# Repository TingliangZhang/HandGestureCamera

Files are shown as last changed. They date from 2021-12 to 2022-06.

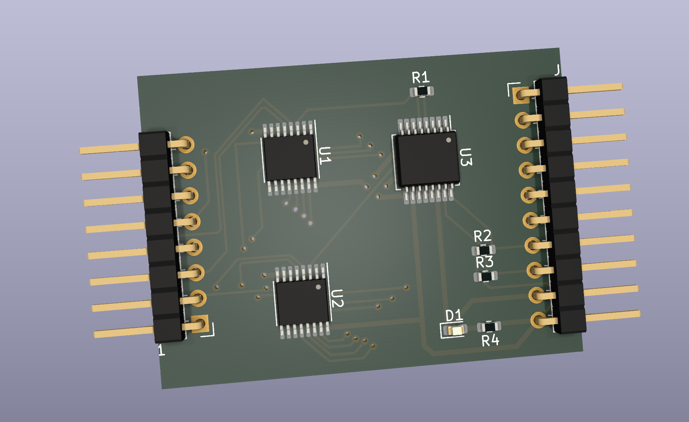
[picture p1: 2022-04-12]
宣传素材/屏幕截图 2022-04-12 194014.png

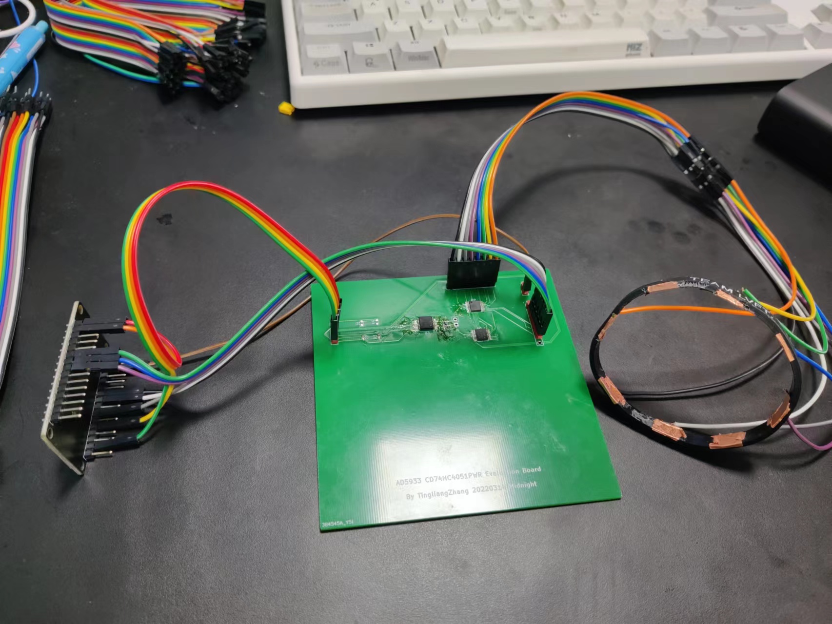
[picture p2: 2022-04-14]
宣传素材/手环V1实物图.jpg

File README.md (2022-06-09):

# HandGestureCamera

## BP相关

主控芯片及PCB上外围电路 约100 其中包括：

| 名称 | 作用 | 估算BOM价格/RMB |
| --- | --- | --- |
| ESP32-WROOM | 主控兼Wifi+蓝牙通信 | 13 |
| 网络分析仪或FPGA替代品  | 测量阻抗 | 20-100 |
| 高频多路选通器 | 两两选通电极 | 5x2 |
| PCB SMT及供电等部分元件 | 集成化 | 10 |

电极及外壳代工 10 

物流及营销费用 10

## 肌电技术方案

测试仪器：[LCR/阻抗分析仪](https://www.hioki.cn/html/methods/power.html)

LCR是单一频率下的阻抗分析仪

复现一款PCB：

[AD5933](https://www.analog.com/cn/products/ad5933.html)+[ADG1608](https://www.analog.com/cn/products/adg1608.html) 

AD5933

I2C通信

ADG1608

EN高电平使能 A2A1A0选通 每片占用4pin数字输出

Arduino采用[Seeed XIAO RP2040](https://www.seeedstudio.com/XIAO-RP2040-v1-0-p-5026.html)

3+3+EN数字输出，2xI2C，2xUART，正好占满qwq

或者希望引脚宽裕一点直接用[Raspberry Pi Pico](https://www.raspberrypi.com/documentation/microcontrollers/raspberry-pi-pico.html)，还更便宜，但是只有3.3V，PCB这边我I2C用的5V

但是由于RP2040 MCU电压就是3.3，其实XIAO的I2C也不一定能work，Arduino板同理

ADG1608额定电源电压：±15 V/12 V/±5 V，3 V逻辑兼容输入，目前PCB设计可能有问题，单5V输入可能会导致开关出错

想用CD74HC4051这种 8:1, 1-channel analog mutliplexer 单通道模拟多路复用器

首先绝对不能用TMUX1308这种数字多路复用器

其他要考虑的事情：

其次驱动电压

内阻

支持的最大电流

备选项包括：ADG1408YRUZ、CD4051B

参考文档 [ 多路复用器和信号开关词汇表 (Rev. B)](https://www.ti.com.cn/cn/lit/pdf/zhcaad5) 中的解释，可以知道，其实8：1双通道模拟多路复用器更适合，如[CD4097B](https://www.ti.com/product/CD4097B) - 20-V, 8:1 differential, 1-channel analog multiplexer，或 [MUX36D08](https://www.ti.com.cn/product/cn/MUX36D08) - 1pA 开路泄漏电流、36V、8:1 精密模拟多路复用器

在TI的[模拟开关 & 多路复用器](https://www.ti.com.cn/zh-cn/switches-multiplexers/analog/overview.html)中可以挑选，

[TMUX1108](https://www.ti.com.cn/product/cn/TMUX1108) - 3pA 导通状态泄漏电流、5V、±2.5V、8:1、单通道精密多路复用器

[TMUX1208](https://www.ti.com.cn/product/cn/TMUX1208) - 具有 1.8V 输入逻辑的 5V、8:1、单通道通用模拟多路复用器

[TMUX1308](https://www.ti.com.cn/product/cn/TMUX1308) - 具有 1.8V 逻辑电平控制的 5V、8:1、单通道通用多路复用器

最终选定：[TMUX1208](https://www.ti.com.cn/product/cn/TMUX1208) 或 [CD74HC4051](https://www.ti.com.cn/product/cn/CD74HC4051)

[CD74HC4051PWR](https://item.szlcsc.com/328685.html) jlc充足现货，可以优先，另购买平替[74HC4051M/TR SOP-16](https://item.szlcsc.com/520618.html)作为备用，但是封装不同，画两个不同的板子或在同一个板子上面画两个方案。

即[CD74HC4051PWR TSSOP-16](https://item.szlcsc.com/328685.html) + [74HC4051M/TR SOP-16](https://item.szlcsc.com/520618.html) 方案

## Arduino

[arduino-ad5933](https://github.com/mjmeli/arduino-ad5933)

用[Seed XIAO RP2040](https://wiki.seeedstudio.com/XIAO-RP2040/) with Arduino不行，没输出

用[ESP32-DevKitC](https://www.espressif.com/en/products/devkits/esp32-devkitc/overview) with Arduino行，一下子就跑通了，调高波特率到115200还贼快，一句话：ESP32牛逼

ESP32开发板接线：SCL-D22、SDA-D21，5V-VIN，GND-GND

Timer参考ESP32 Arduino Example中的ESP32-Timer-Repeat Timer例程，设置定时器

20220406 Debug了一下午，发现俩问题：写switch不写break、Enable电平搞错了。一句话我是傻子。。。

[CD74HC4051 数据表、产品信息和支持| 德州仪器TI.com.cn](https://www.ti.com.cn/product/cn/CD74HC4051) Debug，发现是低电平Enable，之前板子画错了qwq，现在接了一根GND到板子的EN上面，就好了

| ENABLE | S2 | S1 | S0 | ON CHANNEL |
| --- | ---- | ---- | ---- | --- |
| L | L | L | L | A0 |
| L | L | L | H | A1 |
| L | L | H | L | A2 |
| L | L | H | H | A3 |
| L | H | L | L | A4 |
| L | H | L | H | A5 |
| L | H | H | L | A6 |
| L | H | H | H | A7 |
| H | X | X | X | None |

注意编码中S2是最高位！！！第一版本出错是因为编码反了。

gg，刚刚静电电了一下手环，我怀疑MUX被电坏了或者是芯片完蛋了。。。Z变成了3-4w，最低1w

刚刚换成Mega2560测试了一圈，感觉还是采样频率的问题，Frequency越小，比如1kHz，扫描速度越慢。现在调成10kHz甚至20kHz就好很多了，累加一次，准确度目前看是够用的

## Python数据读取和可视化

用[JupyterLab](https://jupyter.org/)+[Plotly Python Graphing Library](https://plotly.com/python/)做可交互的实时数据可视化。

Pyserial读取收到的数据，以下为数据格式的说明

```
0:1
90: R=348/I=1914  |Z|=102512.95
100: R=102/I=2118  |Z|=93806.21
Frequency sweep complete!
```

A:B 从0-8端口中选通两个，测量这两个端口之间的阻抗。

100: / 101: 当前扫描频率，单位为kHz

R/I  中间原始数据的实部虚部

|Z| 测得的阻抗数据，可以进行归一化，由于短路情况下|Z|= REF_RESIST 即10000

想要更简洁的数据，可以修改ino文件，比如0:1 10000 \n

由于AD5933扫描速度的限制，一次扫描约耗时1.5s

Plotly Python Open Source Graphing Library 示例

[2D Histograms](https://plotly.com/python/2D-Histogram/) 二维直方图表示可视化后的二维空间分布

[Histograms](https://plotly.com/python/histograms/) 为原始数据的可视化直方图，28个数据按照两两之间距离从小到大有序排列

[ML Regression](https://plotly.com/python/ml-regression/) 训练过程和效率可视化

## 应用方向

AR手势识别

手语识别

健康管理：

Use [Skulpt](https://www.skulpt.me/) to measure your body fat percentage and get a personalized workout plan to burn fat and build muscle.

## 手势识别相机手环

使用两个位于手表位置的前视摄像头实时识别手势

用于AR设备的手势识别辅助

技术难点：

受限于手腕视角，只能看到骨骼突起和肌肉拉伸，以及偶尔出现的手指，做模式识别可能会比较困难，不同人可能要单独标定。

动态手势复杂度高，手指关节很多

手势数据集较少，我们这一特定的场景还需要单独采集数据集

手环所在位置一定程度上会影响识别的结果

技术方案：

数据集获取使用Leapmotion提取手势关节数据，结合两个摄像头采集到的信息作为训练集。

1.多模态输入

将若干帧光流图像连接在单张彩色图像的通道维度上，将其作为深度网络的输入，使得输入数据中既包含空间信息又携带时序信息，以此来实现动态手势识别

一个序列不同的模态携带不同的信息，RGB图片包含丰富的颜色和纹理信息，深度图片包含物体的轮廓和深度信息，光流分别描述了像素在x方向与y方向的运动信息。这些数据在信息描述上具有互补性，将它们融合起来，能够有效弥补单一模态数据的局限性。

基于RGB 序列和Depth序列和Flow序列的融合特征进行动态手势识别

2.手部检测器预处理

融合彩色和深度数据的双通道Faster R-CNN手部检测框架

3.基于人工特征的机器学习算法的动态手势建模

经典的方法有规整动态时间(Dynamic Time Warping, DTW)算法、隐马尔科夫模型(Hidden Markov Model, HMM)

这部分可以视能否直接得到手部数据来决定做不做

参考

https://image.hanspub.org/Html/19-1541767_35738.htm

https://www.hindawi.com/journals/tswj/2014/267872/

## 新的肌电方法

Tomo: Wearable, Low-Cost Electrical Impedance Tomography for Hand Gesture Recognition

https://dl.acm.org/doi/10.1145/2807442.2807480

金属电极+双选择器+网络分析仪芯片+ESP32+小锂电

https://www.youtube.com/watch?v=FqgwBc7cGZ8

能不能做连续的

下垂和举起手是否能够鲁棒识别

其他身体部分，比如袜子

这一作老哥后来还做了手表周围的另一只手的触摸识别

https://dl.acm.org/doi/10.1145/2984511.2984568

以及手指是否摸到皮肤的识别

https://dl.acm.org/doi/10.1145/3332165.3347869

和一些导电物体周围贴上电极的识别

https://dl.acm.org/doi/10.1145/3025453.3025842

## 新的想法-手语识别

目标是识别中文手语，关于中文手语的科普参考 [回形针Vol.154 手语的秘密](https://www.youtube.com/watch?v=vpkHTLhuDqg)

发现手语包括手部动作、肢体语言、面部表情

目前ASL图像识别方面做的比较好的是国外的[SignAll](https://www.signall.us/)，看图片是一个Kinect2和俩Realsense D435i，还有一个铁架子打光+架设摄像头，使用者要戴上一个五彩斑斓的手套。国内则是[腾讯优图发布的AI手语翻译机](https://cloud.tencent.com/developer/article/1430241)通过单摄像头识别，但是看起来需要很高的算力，DEMO用的是外星人的笔记本。

其实可以先做ABC的识别：这个是一个很傻的一个一个字母翻译的网页[English to Sign Language (ASL) Translator](https://wecapable.com/tools/text-to-sign-language-converter/)

[Hand Talk Translator](https://play.google.com/store/apps/details?id=br.com.handtalk)是逆向的转换，从文本到动漫人物动作的转换，国内类似产品是[搜狗AI开发平台手语数字人](https://ai.sogou.com/solution/signlanguage_digitalman/)

[手语也能机器翻译了！机器学习手势识别功能了解一下](https://blog.51cto.com/u_14815220/3451551) 华为机器学习（ML Kit）提供手部关键点识别服务，可用于手语识别。手部关键点识别服务能识别手部21个关键点，通过每个手指的方向和手语规则作比较去找手语字母表。

后期可以做根据国家通用手语词典来做8k+的词组识别。

申专利、发顶会、打比赛

## 竞品

[Tenzr: A Fun and Efficient Way to Regain Mobility and Function](https://tenzrhealth.com/) 主打手腕康复，就离谱，感觉是智商税，技术方案是IMU

[TENZR, the next generation gesture recognition wrist-band for VR AR, to be presented at CES 2018](https://www.prnewswire.com/news-releases/tenzr-the-next-generation-gesture-recognition-wrist-band-for-vr-ar-to-be-presented-at-ces-2018-300572362.html)

这个报告里面的BioInteractive Technologies Inc.和上一个是同一家智商税公司，所以这个只是个想法，没做。

[Myo Gesture Control Armband review](https://www.digitaltrends.com/pc-accessory-reviews/myo-gesture-control-armband-review/) EMG原理，很多年前就比较完善了，但是已经停产了xs，估计无了

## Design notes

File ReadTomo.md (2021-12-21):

Tomo: Wearable, Low-Cost Electrical Impedance Tomography for Hand Gesture Recognition

https://dl.acm.org/doi/10.1145/2807442.2807480

是否需要像[Touché](https://dl.acm.org/doi/10.1145/2207676.2207743)一样去扫频

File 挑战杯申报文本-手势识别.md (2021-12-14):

# 挑战杯项目申报-手势识别

SignWatch：一种基于断层扫描的可穿戴手势识别

[第40届挑战杯报名开始-清华美院艺协](https://mp.weixin.qq.com/s/xyTMBz-5uR9o7P9dYUQgTA)

## 创新性产品或服务简介

中国有2700万以上的聋哑人，他们主要使用手语进行交流。近年来国内外研究机构和企业逐渐开始关注手语翻译的可能性，目前较为成熟的方向是深度摄像头视觉识别，但是这种方法需要较多的外部设备，如多个深度摄像头、补光灯、性能强大的PC以及固定上述设备的支架，无法应用在日常交流中。本项目提出了一种基于断层扫描的穿戴式手势识别，借鉴CT、PET、MRI（核磁共振）等医学影像设备使用的断层扫描算法，通过环状排布的电极采集阻抗信息逆推肌肉收缩情况，从而实现使用可穿戴手环识别手势，进一步结合手臂状态实现手语实时翻译。可穿戴手语翻译能够帮助手语使用者在日常生活中与其他语言使用者进行交流，有着广阔的应用前景、众多的目标用户和极大的社会价值。

## 项目市场前景和社会效益预测分析

中国有2700万以上的聋哑人，这一数字还在不断增长，作为占中国人口近2%的群体，另据WHO估计，到2050年，全球将有超过7亿人，即十分之一人口，发生残疾性听力损失。但我们在生活中很少见到他们，一个重要的原因就是听觉功能障碍者或言语功能障碍者使用手语作为常用的沟通方式，手语作为一种独立语言，学习成本较高，急需一款能够打通中英文使用者和手语使用者之间语言屏障的产品出现，来帮助手语使用者更好的融入社会。

本项目旨在提供一种绝大多数家庭可负担的可穿戴的手语翻译工具，并考虑到后续的更新换代，按照每人100美元计算，仅中国大陆就有约30亿美元的市场容量，如果考虑到连带服务和同样目标用户群体产品空间，这将是一个逾百亿美元的市场。

初期我们和特殊学校合作，在测试迭代产品的同时，了解听觉功能障碍者或言语功能障碍者的需求，也为中国的特殊群体尽自己的一份力。

## 创业团队基本情况

本团队成员均来自清华大学美术学院，团队成员有工科、设计双背景，有着丰富的交互设备开发相关项目的经验。

团队曾获得清华挑战杯特奖、清华校友三创大赛总决赛种子组十强、互联网+创新创业大赛北京市十佳团队、中美青年创客大赛全国总决赛优胜奖，是一支久经沙场的创新创业团队。

万雪鸽，美院产品设计专业在读，具备优秀的设计思维和熟练的设计技能。曾立项过两次国家级大学生创业创新项目计划、两次产品设计相关的srt并参与了完整的创新过程，具备交互设备开发、产品开发的能力和经验。

林易佳，美院产品设计专业在读，曾参加过挑战杯大赛并取得三等奖。

粟艺薇，美术学院展示设计学生，具备产品设计思维能力及三维制作能力。曾立项创业实践项目，参加srt“基于人工智能的在线教育产品设计”交互界面设计，参与工艺美术馆空间展示设计，成渝铁路逻辑梳理及空间设计。

张庭梁，于2020年本科获清华大学电气工程及其自动化工程学士学位，清华大学美术学院信息艺术设计交叉学科研究生，目前在清华大学未来实验室。入选星火计划十二期（“科技创新，星火燎原”清华大学学生创新人才培养计划）。现任清华大学“未来通信”学生科技兴趣团队理事长，曾任清华大学“天空工场”学生科技兴趣团队“未来航空队”队长。2018年暑假在劳伦斯 - 伯克利国家实验室和加州大学伯克利分校 MSC Lab暑期研修。

曾获清华大学第38届“挑战杯”学生课外学术科技作品竞赛 特等奖、清华大学2020-2021年度优秀科技之星、第六届清华校友三创大赛总决赛 互联网与新媒体 种子组 十强奖、中美青年创客大赛全国总决赛 优胜奖、互联网 + 创新创业大赛北京市十佳团队、ABB大学生创新大赛全国总决赛三等奖(全国前六)等诸多科技创新创业奖项。

## 项目方案

手语（sign language、signed language、signing）是一种不使用听觉-语音，而使用视觉-手势模式——以肢体动作、脸部表情来表达传达意义意思使用的的语言。主要使用者和使用对象，是听觉功能障碍者或言语功能障碍者。对一般大众而言，手语不算通用；在聋聩人士的社群，手语则是相当常见的沟通方式。手语并非世界共通，手语会像口语一样，依照地区的不同，发展一套属于各该地区的手语。随着各种手语发展，如今有数百种手语在聋人社会中通用。

口语语言的必要成分是语音、词汇和语法。而手语就以不同的“手形”和动向代替了语音这部分的分工。有些地方的手语研究工作者会把基本手形加以编码（以美国手语字母为基础），情况就像口语语言使用者为每个音素标音，技术上，手语使用者就可以使用这些“音标”，再加上箭头以表示动向，作为以手语为本的简单的书面记录形式，而不需要动辄拍照或画图来作书面记录。虽然这种情况并不普遍，各地手语也暂没发展出以手语为本的规范通用文字，但技术上可行。邓慧兰编撰的《香港手语词典》(Hong Kong Sign Language: a trilingual dictionary)就以这种把基本手形编码的方法，作为词典的检索索引。

与大多数其他手语一样，中国手语（英语：Chinese Sign Language）主要是通过手势和动作结合面部表情来表达的。中国手语制定的目标是，解决中国各地的流行手语手势不一致、聋人学习科学文化知识及交往不便的问题。2018年7月1日，中国实施《国家通用手语常用词表》和《国家通用盲文方案》作为语言文字规范发布。2021年3月1日，国家语委语言文字规范《〈中华人民共和国国歌〉国家通用手语方案》（GF0024-2020）正式实施。

根据WHO统计，全球有15亿人患有某种程度的听力损失，其中约4.3亿人需要针对听力损失的康复服务。到2050年，预计将近25亿人有某种程度的听力损失，至少7亿人需要听力康复。听力丧失可能由遗传、出生时的并发症、某些传染病、慢性耳感染、暴露于大的声响、使用耳毒性药物和衰老引起。全世界人口的5%以上，即4.3亿人，需要康复治疗，以解决他们的残疾性听力损失（4.32亿成人，3400万儿童）。据估计，到2050年，将有超过7亿人，即十分之一人口，发生残疾性听力损失。

完整的手语包括手部动作、肢体语言、面部表情三部分，其中表达内容丰富度方面手部动作大于肢体语言大于面部表情，通过手部动作和上肢即可完成绝大部分的表意。目前穿戴式手势识别是整个流程中的技术难点所在。

我们提出使用环形均匀排布的8个电极作为采样点，通过两个8选1MUX依次选通其中两个电极，并使用网络分析仪监测这两个电极之间的实时阻抗，获得28个阻抗数据，使用图像重建算法重建截面的肌肉状态，从而获取目前手势。初步的实验已经证明此方法的科学性和可行性。

计算机体层成像（Computed Tomography，简称CT）又称计算机断层扫描，是一种影像诊断学的检查。这一技术曾被称为计算机轴向断层成像（Computed Axial Tomography）。它使用从不同角度进行的许多X射线测量值的计算机处理组合来生成特定扫描区域的横截面（断层）图像（虚拟“切片”） 物体，使用户无需切割即可看到物体内部。

正电子发射断层扫描（英语：Positron emission tomography，简称PET）简称正子断层造影、正电子成像术，是一种核医学临床检查的成像技术。PET技术是目前唯一的用解剖形态方式进行功能、代谢和受体显像的技术，具有无创伤性的特点并能提供全身三维和功能运作的图像。正电子发射计算机断层扫描既是医学也是研究的工具。在肿瘤学临床医学影像和癌扩散方面的研究方面有着大量的应用。

我们参考CT和PET的图像重建部分的算法，作为一种不完全数据采样，准确来说是稀疏角度均匀采样，稀疏角度重建问题图像重建方法中, 迭代重建最经典的方法是 Gorden等提出的代数重建法(algebra reconstruction technique, ART)，ART算法虽然适合投影数据不完全、投影角度缺失以及投影间隔不均匀等场合的图像重建, 但其计算量大, 重建速度慢。

2006 年 Candes 等 对 Kashin 提出的信号稀疏和逼近理论进行了深 入研究, 提出了一种新的信息获取理论-压缩感知 (compressed sensing, CS): 只要信号在某一个正交空间具有稀疏性, 就可以较低的频率采样信号高概率重构原始信号. 根据CS理论, 在迭代重建中 增加关于稀疏变换后图像的稀疏性约束, 可以解决内部问题、少视角问题等不完备投影数据的精确重建问题。

在以上算法的加持下，我们可以进一步消除噪声，获得更加清晰的肌肉断层扫描图像，从而实现趋于连续的手势识别，相比于离散的模式识别，在未来的进一步应用中更为普适。

同时我们这套系统还可以在AR、VR的手势识别中获得广泛应用，由于目前包括Hololens在内的AR眼镜都是通过前置摄像头识别手势，需要将手举起来才能操作，大大增加了用户的操作难度，手环或手表的识别是更自然更符合人机工程学的方式。

在进一步开发后，这一扫描可以方便的移植到其他场景，如脚踝、脖子等处，实现更为丰富的动作采集和应用。

## 项目实施风险预测及应对措施

可能会面临的产品竞争：项目目前市场上已有视觉相关解决方案，可能会产生竞争。我们团队有软硬件设计和产品设计的知识储备、经验，拥有的技术优势能够帮助我们更好的在市场上立足。更重要的是，本项目采用的断层扫描手势识别方案无需假设过多的外部设备，在佩戴手表和肩带的情况下即可进行手势识别，场景更加灵活，在一些日常生活交流场景中更是不二的选择。

可能面临的项目落地难题：可能难以打开市场或进行供应链管理。我们团队有从事过供应链管理和创业经验的成员，可以使我们少走弯路。

另外由于用户群体的特殊性，后续的测试及用户体验环节可能比较难开展：由于二作所在实验室——未来实验室常年从事无障碍设计，同时我们和一些特殊学校有密切的联系，在落地方面优势明显。

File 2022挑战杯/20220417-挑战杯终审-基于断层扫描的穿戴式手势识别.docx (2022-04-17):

基于断层扫描的穿戴式手势识别

万雪鸽 张庭梁 王喆隆 林易佳 粟艺薇

一、概述

本项目旨在设计一款可以实现手语实时翻译的手势识别智能手环，帮助手语使用者在日常生活中与其他语言使用者进行顺畅的交流。我们提出了一种基于断层扫描的穿戴式手势识别，借鉴借鉴CT、PET、MRI（核磁共振）医学影像设备使用的断层扫描算法，通过环状排布的电极采集阻抗信息逆推肌肉收缩情况，从而实现使用可穿戴手环识别手势，进一步结合手臂状态实现手语实时翻译。有着广阔的应用前景、众多的目标用户和较大的社会价值。

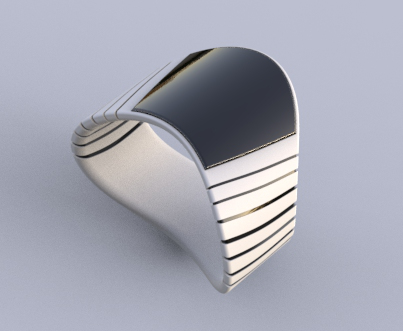
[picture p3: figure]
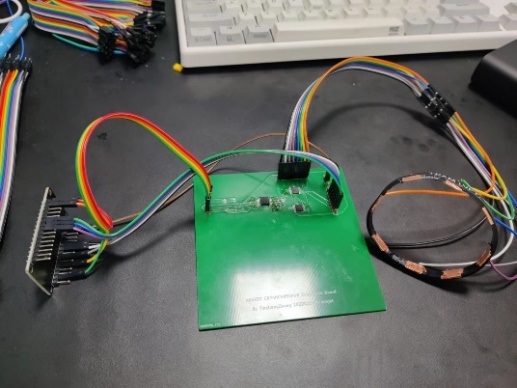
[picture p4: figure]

产品概念图 初代实体图

二、项目背景

1数量庞大的目标群体

根据全国第二次残疾人抽样调查数据，中国有2700万以上的聋哑人，大约占全国人口的2%，这一数字还在不断增长，另据WHO估计，到2050年，全球将有超过7亿人，即十分之一人口，发生残疾性听力损失。但我们在生活中很少见到他们，一个重要的原因就是听觉功能障碍者或言语功能障碍者使用手语作为常用的沟通方式，手语作为一种独立语言，学习成本较高，虽然我国信息无障碍领域的投入在逐渐增加，但全国致力于听障者专业服务人士仍只有约一万名，大部分公共服务没有配备专门的便利设施。所以我们急需一款能够打通中英文使用者和手语使用者之间语言屏障的产品出现，来帮助手语使用者更好的融入社会。

2当前手势识别技术的局限性

由于VR技术的兴起，近年来国内外研究机构和企业逐渐开始关注手识别，目前手势识别的方法主要分为肌电传感、摄像头图像识别、弯曲传感等几个方向，但是目前这些方法都存在一些问题导致他们不能被用在我们这一应用场景中，具体来说是肌电不准确、相机需要外置、弯曲传感体积太大而且不鲁棒。

而手语翻译的核心问题在于手势识别。目前到手势识别方式包括机电传感，摄像头图像识别，弯曲传感等方式。但是存在肌电信号不准确，相机需要外置，弯曲传感体积太大而且鲁棒性低等问题。以这款目前已经生产并使用的产品为例，如果想要获得精准的识别，需要有复杂的设备 清晰的光源和固定的场景

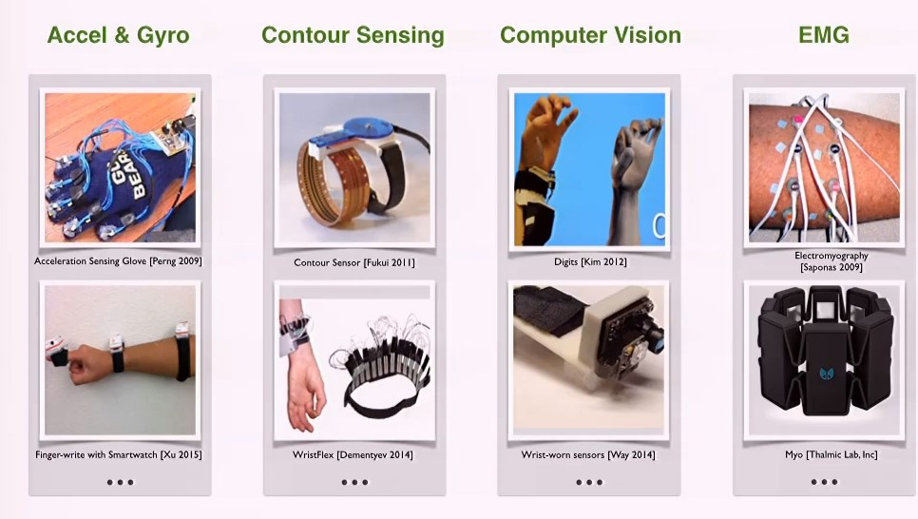
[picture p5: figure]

3 当前智能手语翻译设备

相关产品主要分为基于计算机视觉记录和基于数据的手套记录两种不同的类型。

对于听障人士来说，高昂的价格、笨重的设备、不精准的识别与翻译和有限的使用场景让以上产品难以在现实中使用。

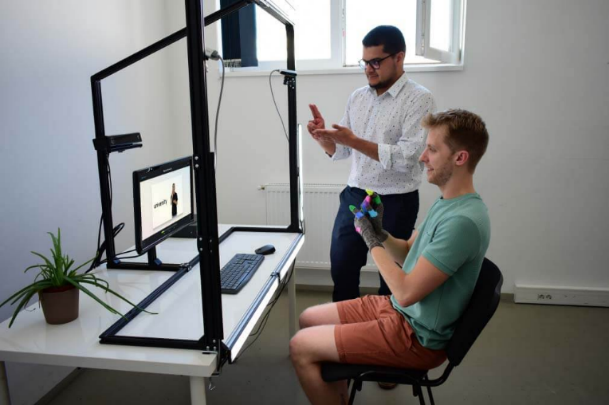
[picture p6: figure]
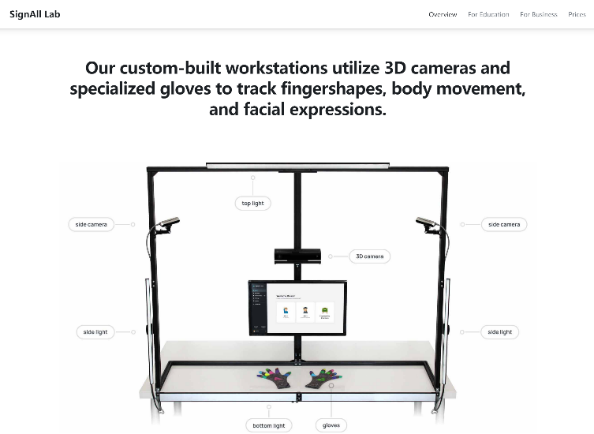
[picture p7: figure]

4 断层扫描技术应用的可行性

我们提出使用环形均匀排布的8个电极作为采样点，通过两个8选1MUX依次选通其中两个电极，并使用网络分析仪监测这两个电极之间的实时阻抗，获得28个阻抗数据，使用图像重建算法重建截面的肌肉状态，从而获取目前手势。初步的实验已经证明此方法的科学性和可行性。我们希望借助此技术给绝大多数手语使用者提供一种可负担的可穿戴的手语翻译工具。

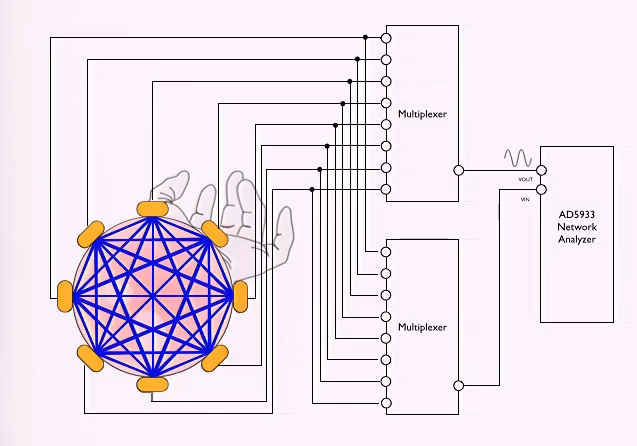
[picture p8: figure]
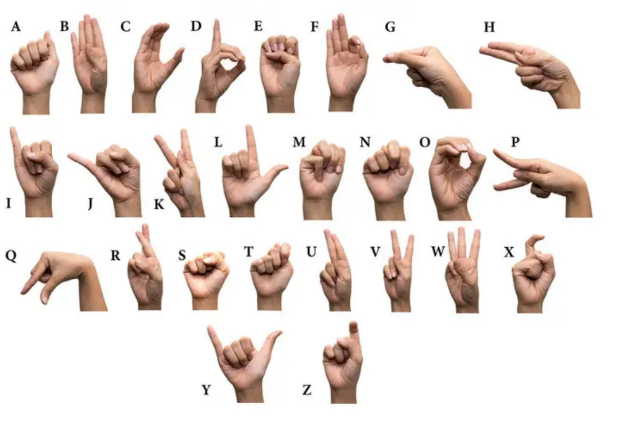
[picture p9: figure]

三、工作介绍

1 前期调研

手语是听觉功能障碍者或言语功能障碍者使用的交际工具，是人们利用手形、手的位置、手的移动、手掌的朝向，再配合以面部表情和身体姿态，按照一定的语法规则来表达特定的意思。对手语的识别不仅包括手部肌肉的捕捉与识别，还需要识别手臂的运动轨迹、左右手的相对位置、使用者的面部表情和手语与口语语义语法的自然转化，因此对手语的识别与翻译困难重重。

另外，手语并非世界共通，手语会像口语一样，依照地区的不同，发展一套属于各该地区的手语。随着各种手语发展，如今有数百种手语在聋人社会中通用。这也为手语的翻译增加了难度。

经过我们对手语的学习和系统梳理，我们发现在以上众多因素中，手语中手形变化的占比最多，左手是主要手，右手是辅助手，面部表情只做补充。另外由于手语因地域不同而有很大的变化，所以现在听障人士在遇到不会打的手语词汇时会使用手指字母代替，聋校教师也会以手指字母为媒介教导聋人口语与手语的转换，手指字母在听障人士间的使用频率很高。因此我们决定以26个手语字母为基础进行手语的识别与翻译。

2 嵌入式电路设计和制作

使用嵌入式芯片和高速ADC做阻抗采集

同时采用扫描的思路来获取各个方向的Tomography数据

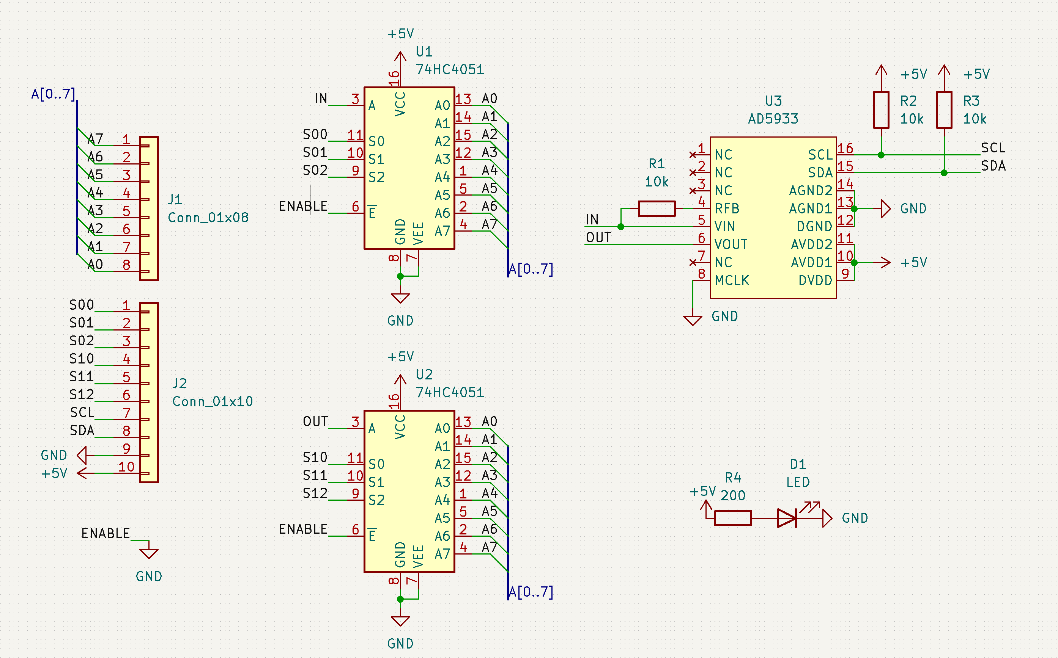
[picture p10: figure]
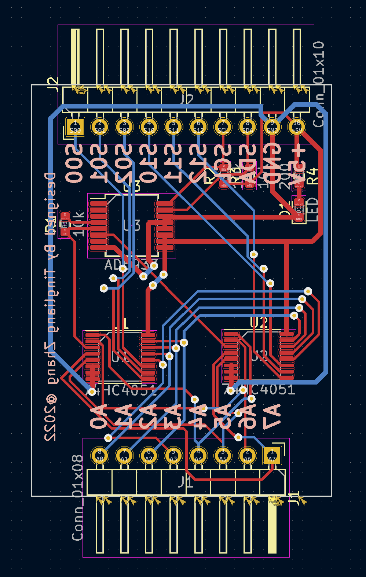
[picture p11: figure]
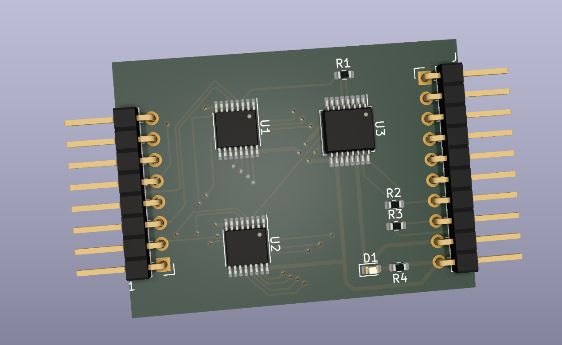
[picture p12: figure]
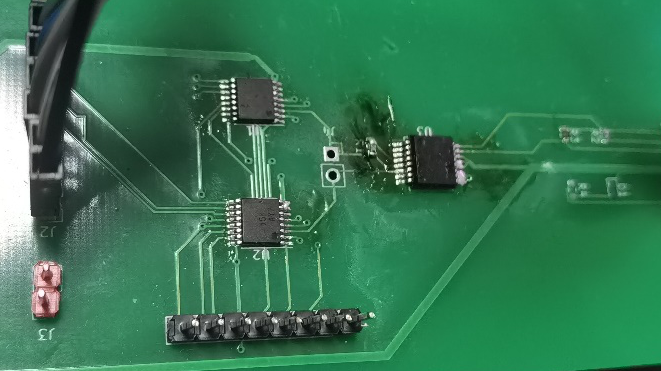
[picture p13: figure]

我们使用嵌入式芯片和高速ADC做阻抗采集，以上为手环小板原理图电路图和实物图，同时我们采用了扫描的思路来获取各个方向的Tomography数据：

3 手环产品设计

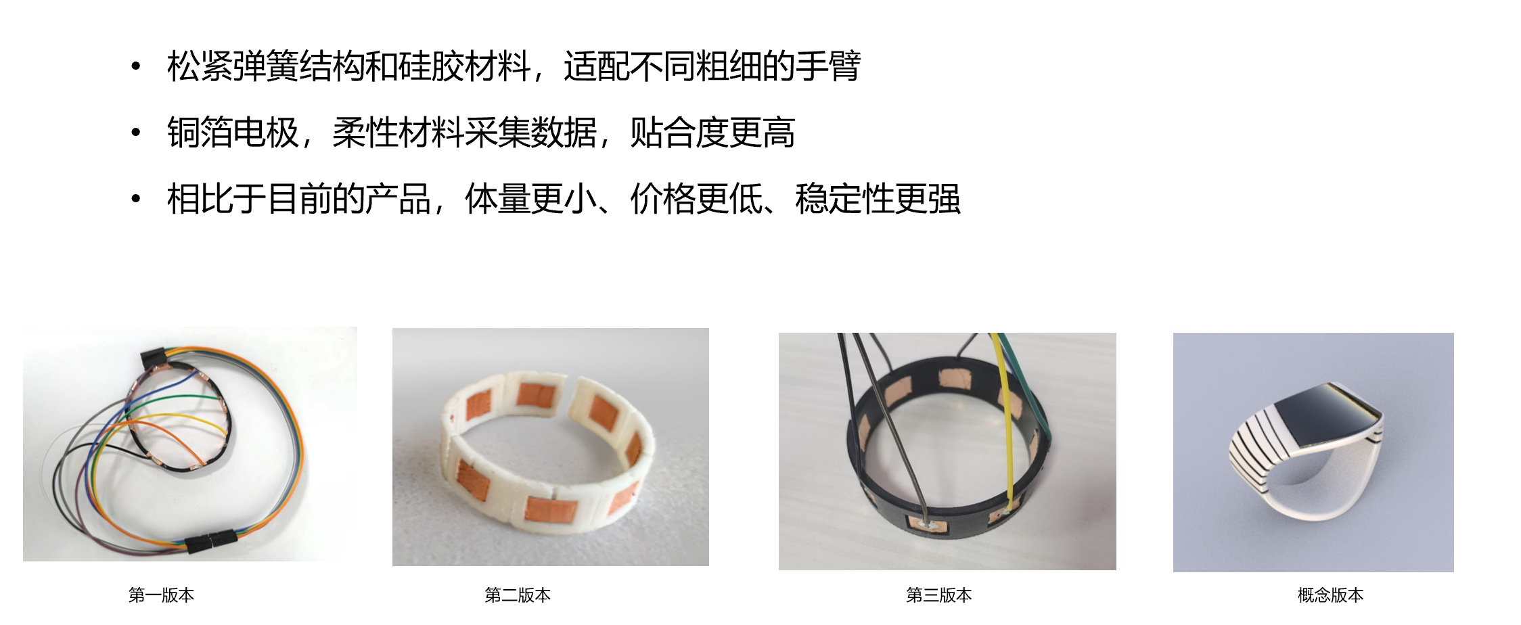
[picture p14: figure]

4 数据采集和可视化

我们使用上述嵌入式系统采集了大量训练数据并进行可视化和打标：

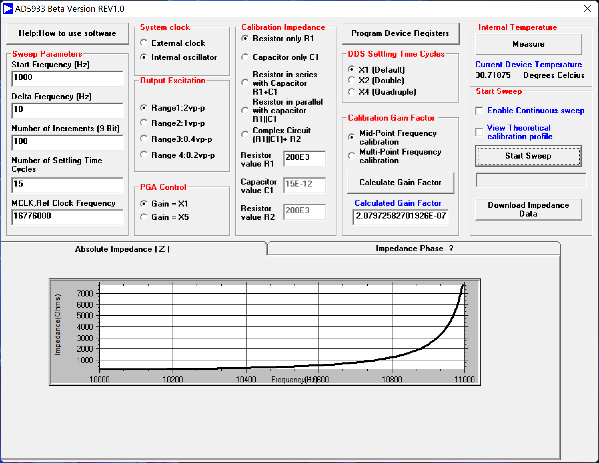
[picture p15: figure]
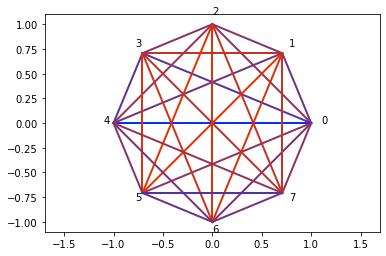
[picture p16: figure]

5 数据处理和机器学习

我们使用每帧28个特征点作为原始数据，无重复的对其中每一对数据做差得到378组数据，将这些数据集合进SVM训练，最终输出分类结果，并且产生了一些可视化效果以供鉴别过程中的正误。

四、成果总结

我们提出了一套识别手势的紧凑解决方案，巧妙地利用机器学习、图形学和医学影响方面的知识设计算法，同时设计了微型嵌入式系统和可靠的产品外观和结构，以期此技术能在无障碍交互如手语识别以及AR交互方面有所应用。

五、未来展望

目前我们先验证了这一想法的可行性，但由于时间紧迫以及疫情导致的代工厂停工，我们依然有不少可以改进的地方：

嵌入式系统方面，可以通过更精细的时序逻辑实现更高的刷新率和更具性价比的方案，同时可以考虑使用FPC制作柔性电路板。

算法方面，在采集更多的数据之后我们可以训练出更精准普适的识别模型。

产品设计方面，可以在目前硅胶3D打印模型的基础上做出更符合用户逻辑的产品。

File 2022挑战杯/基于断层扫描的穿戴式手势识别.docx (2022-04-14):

基于断层扫描的穿戴式手势识别

团队成员：万雪鸽 张庭梁 王喆隆 林易佳 粟艺薇

一、概述

本项目旨在设计一款可以实现手语实时翻译的手势识别智能手环，帮助手语使用者在日常生活中与其他语言使用者进行顺畅的交流。我们提出了一种基于断层扫描的穿戴式手势识别，借鉴借鉴CT、PET、MRI（核磁共振）医学影像设备使用的断层扫描算法，通过环状排布的电极采集阻抗信息逆推肌肉收缩情况，从而实现使用可穿戴手环识别手势，进一步结合手臂状态实现手语实时翻译。有着广阔的应用前景、众多的目标用户和极大的社会价值。

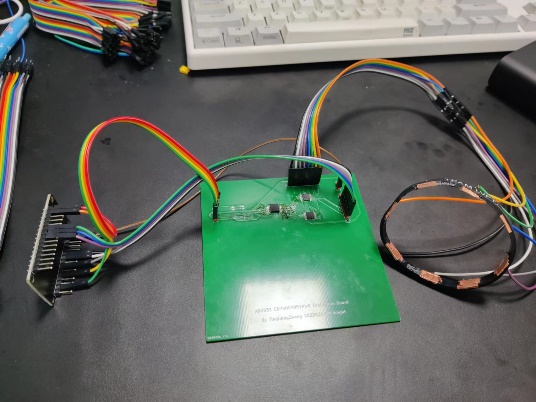
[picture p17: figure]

产品概念图 初代产品实体图

二、项目背景

1数量庞大的目标群体

根据全国第二次残疾人抽样调查数据，中国有2700万以上的聋哑人，大约占全国人口的2%，这一数字还在不断增长，另据WHO估计，到2050年，全球将有超过7亿人，即十分之一人口，发生残疾性听力损失。但我们在生活中很少见到他们，一个重要的原因就是听觉功能障碍者或言语功能障碍者使用手语作为常用的沟通方式，手语作为一种独立语言，学习成本较高，虽然我国信息无障碍领域的投入在逐渐增加，但全国致力于听障者专业服务人士仍只有约一万名，大部分公共服务没有配备专门的便利设施。所以我们急需一款能够打通中英文使用者和手语使用者之间语言屏障的产品出现，来帮助手语使用者更好的融入社会。

2当前手势识别技术的局限性

由于VR技术的兴起，近年来国内外研究机构和企业逐渐开始关注手识别，目前手势识别的方法主要分为肌电传感、摄像头图像识别、弯曲传感等几个方向，但是目前这些方法都存在一些问题导致他们不能被用在我们这一应用场景中，具体来说是肌电不准确、相机需要外置、弯曲传感体积太大而且不鲁棒。


目前常见的手势识别技术

3 当前智能手语翻译设备

国内外有很多项目致力于将手势识别技术应用在手语翻译中，市场上也有几款智能手语翻译设备，当前根据录入形式的不同, 而主要分为基于计算机视觉记录和基于数据的手套记录两种不同的类型，基于数据手套的这种识别率比较高而且比较精准但是数据手套穿戴起来比较麻烦, 而且用户活动区域受限。基于计算机识别的理论系统比较方便用户使用, 但是在识别精度低, 数据手套相对较弱。对于听障人士来说，高昂的价格、笨重的设备、不精准的识别与翻译和有限的使用场景让以上产品难以在现实中使用。

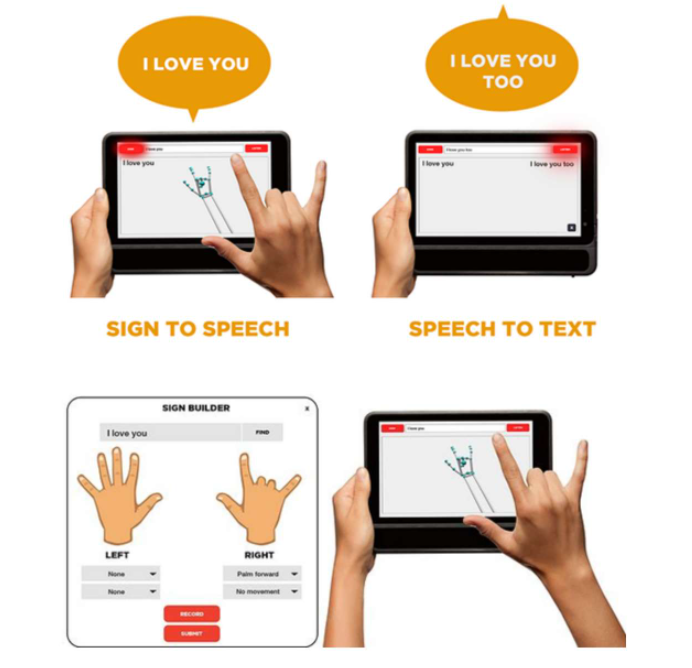
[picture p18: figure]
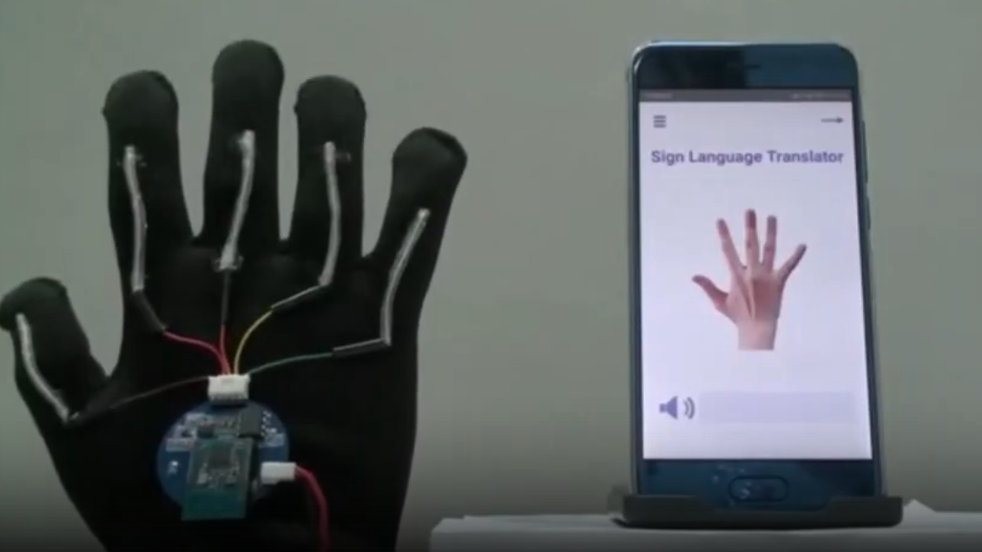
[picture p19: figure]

基于计算机视觉的手语翻译（罗彻斯特理工学院） 基于数据的手套记录翻译（美国加州大学）

最近比较引人关注的是应用在冬奥赛事播报央视新闻手语主播， 这位由“百度智能云曦灵”打造的首个AI手语主播，面对主持人不断抛出的超高速顺口溜，也能立马就能做出反应，表现出流畅、精准的业务能力。“冬奥手语播报数字人”系统以超大规 模预训练模型为核心技术，通过语义蒸馏及手语翻译快编模型，实现新闻播报语音蒸馏成语义高 度接近的手语文字，并翻译成符合手语习惯的语序。最终，手语数字脑可以通过计算机模仿听障 人士的大脑，进行手语播报驱动。这一产品是由语音输入转为动作输出，虽然与我们的整体交互方式相反，但是其对手语体系的整理和口语手语的转换也为我们的可行性提供了佐证，对我们未来的工作提供了参照。

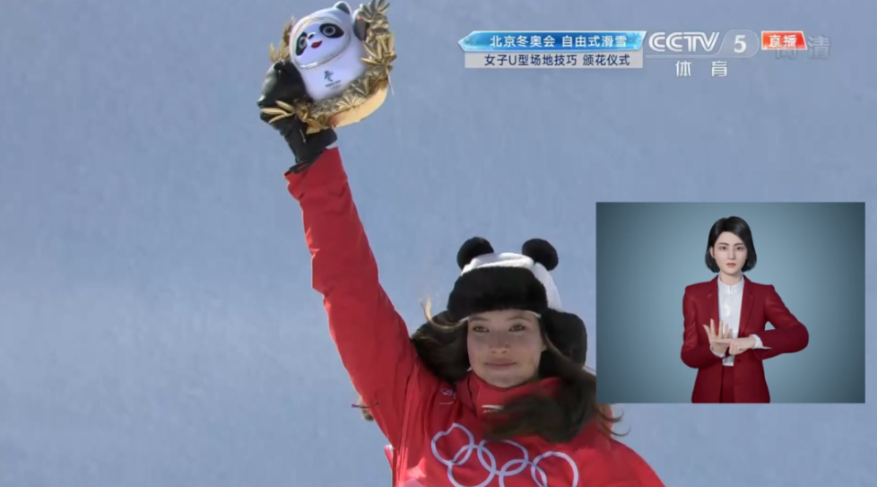
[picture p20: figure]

AI主播在冬奥会期间的应用

4 断层扫描技术应用的可行性

我们提出使用环形均匀排布的8个电极作为采样点，通过两个8选1MUX依次选通其中两个电极，并使用网络分析仪监测这两个电极之间的实时阻抗，获得28个阻抗数据，使用图像重建算法重建截面的肌肉状态，从而获取目前手势。初步的实验已经证明此方法的科学性和可行性。我们希望借助此技术给绝大多数手语使用者提供一种可负担的可穿戴的手语翻译工具。

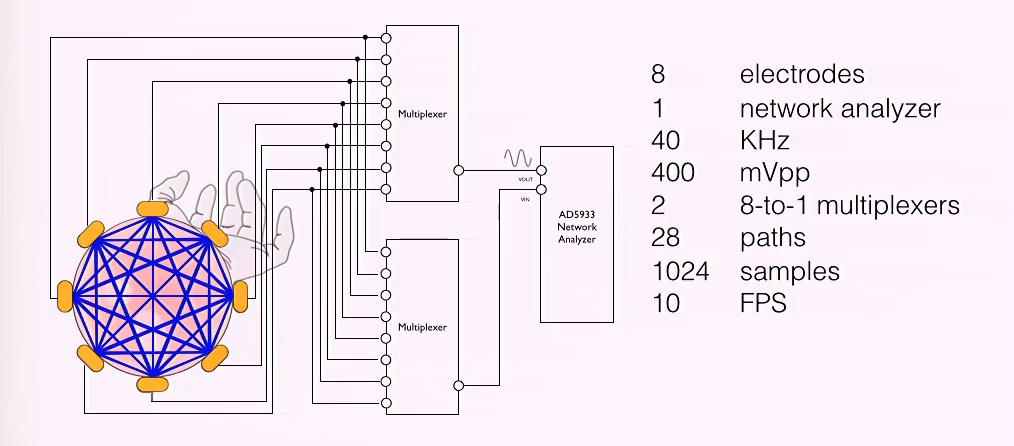
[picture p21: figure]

三、工作介绍

1 前期调研

手语是听觉功能障碍者或言语功能障碍者使用的交际工具，是人们利用手形、手的位置、手的移动、手掌的朝向，再配合以面部表情和身体姿态，按照一定的语法规则来表达特定的意思。对手语的识别不仅包括手部肌肉的捕捉与识别，还需要识别手臂的运动轨迹、左右手的相对位置、使用者的面部表情和手语与口语语义语法的自然转化，因此对手语的识别与翻译困难重重。

另外，手语并非世界共通，手语会像口语一样，依照地区的不同，发展一套属于各该地区的手语。随着各种手语发展，如今有数百种手语在聋人社会中通用。这也为手语的翻译增加了难度。

经过我们对手语的学习和系统梳理，我们发现在以上众多因素中，手语中手形变化的占比最多，左手是主要手，右手是辅助手，面部表情只做补充。另外由于手语因地域不同而有很大的变化，所以现在听障人士在遇到不会打的手语词汇时会使用手指字母代替，聋校教师也会以手指字母为媒介教导聋人口语与手语的转换，手指字母在听障人士间的使用频率很高。因此我们决定以26个手语字母为基础进行手语的识别与翻译。

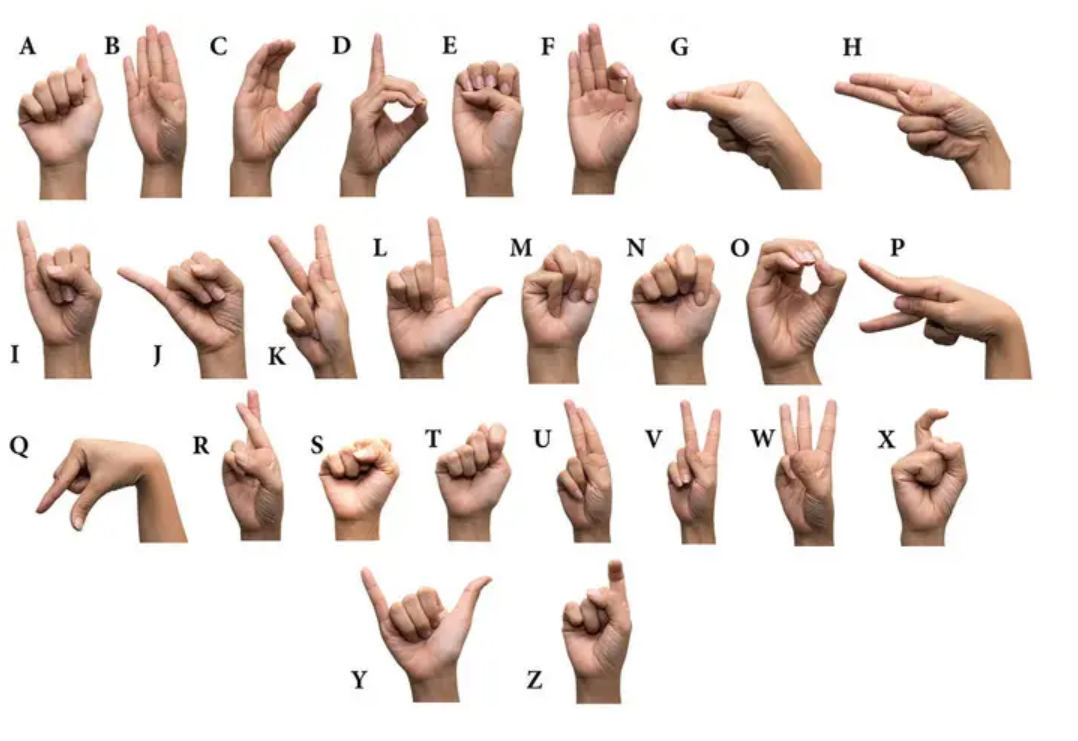
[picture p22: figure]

世界通用手指字母表

2 嵌入式电路设计和制作

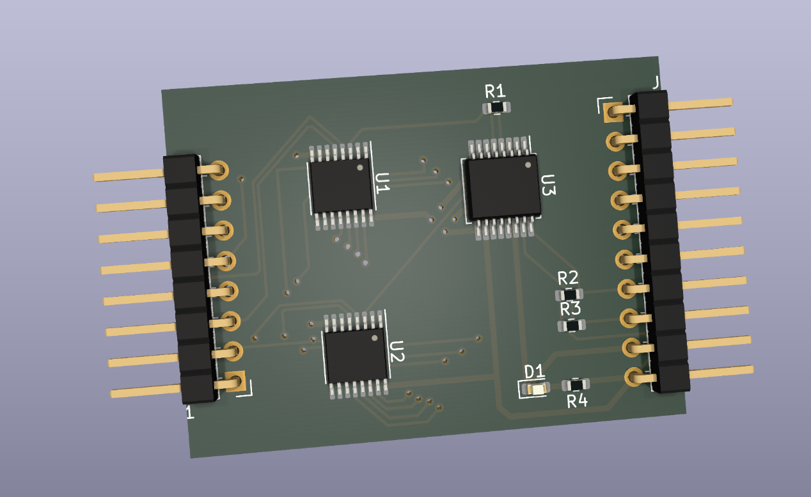
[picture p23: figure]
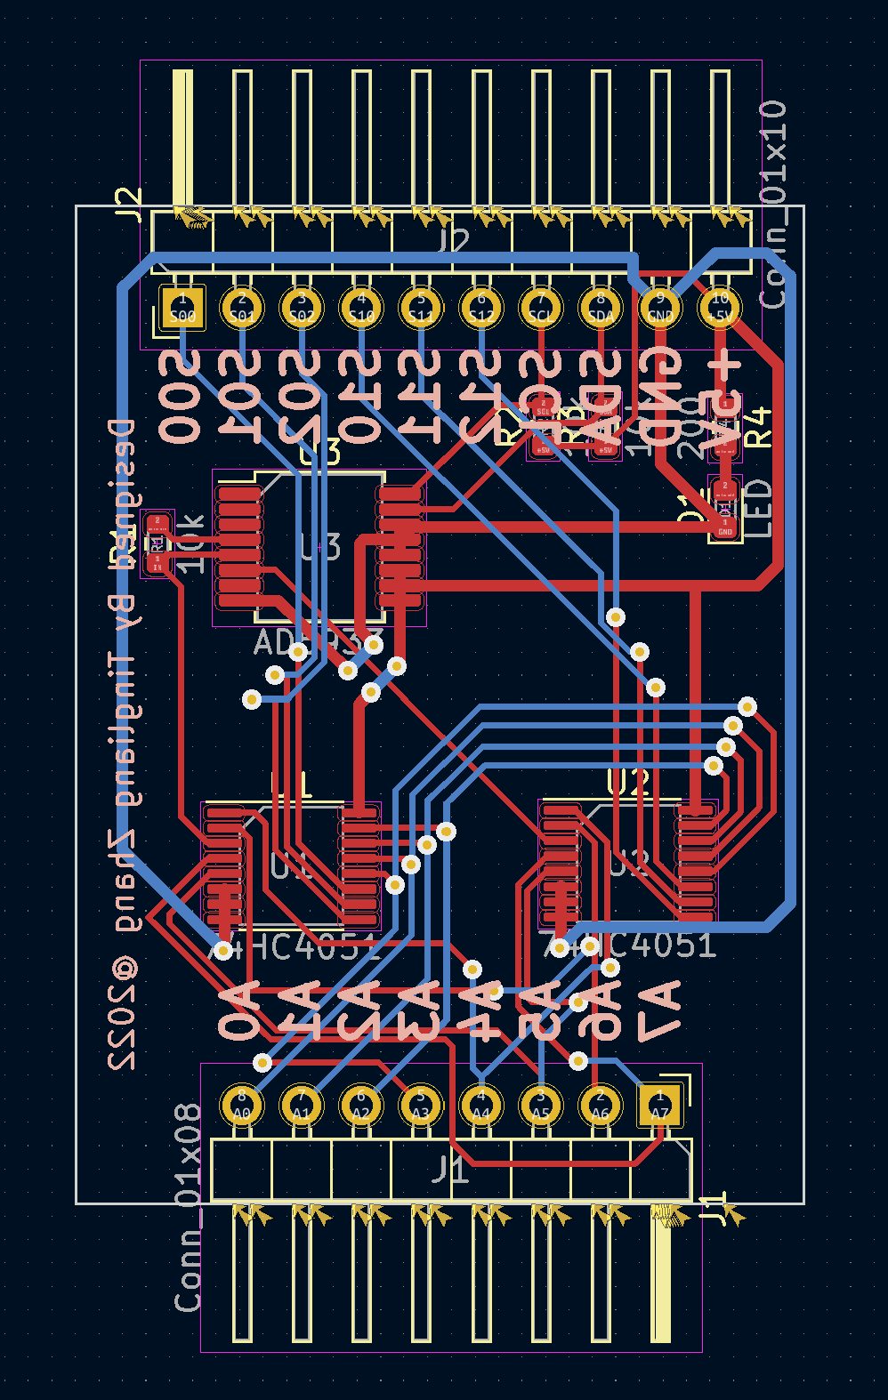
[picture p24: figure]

我们使用嵌入式芯片和高速ADC做阻抗采集，以上为手环小板原理图电路图和实物图

同时我们采用了扫描的思路来获取各个方向的Tomography数据：

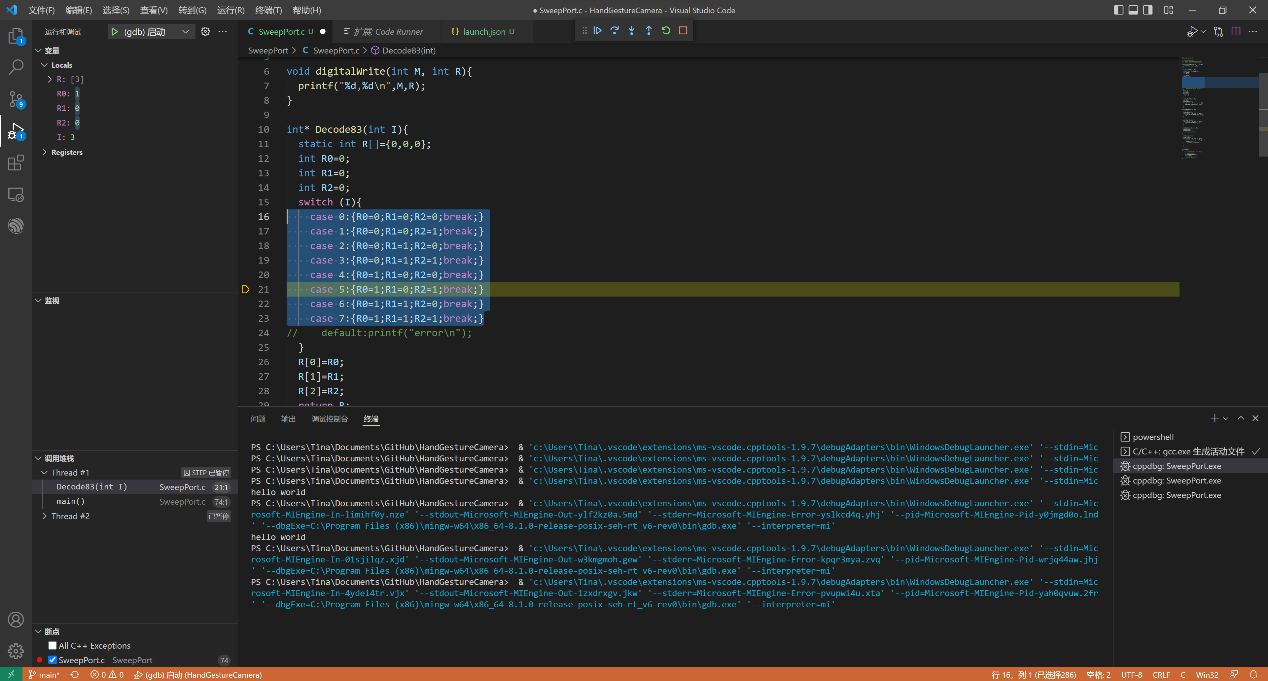
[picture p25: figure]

3 手环产品设计

4 数据采集和可视化

我们使用上述嵌入式系统采集了大量训练数据并进行可视化和打标：

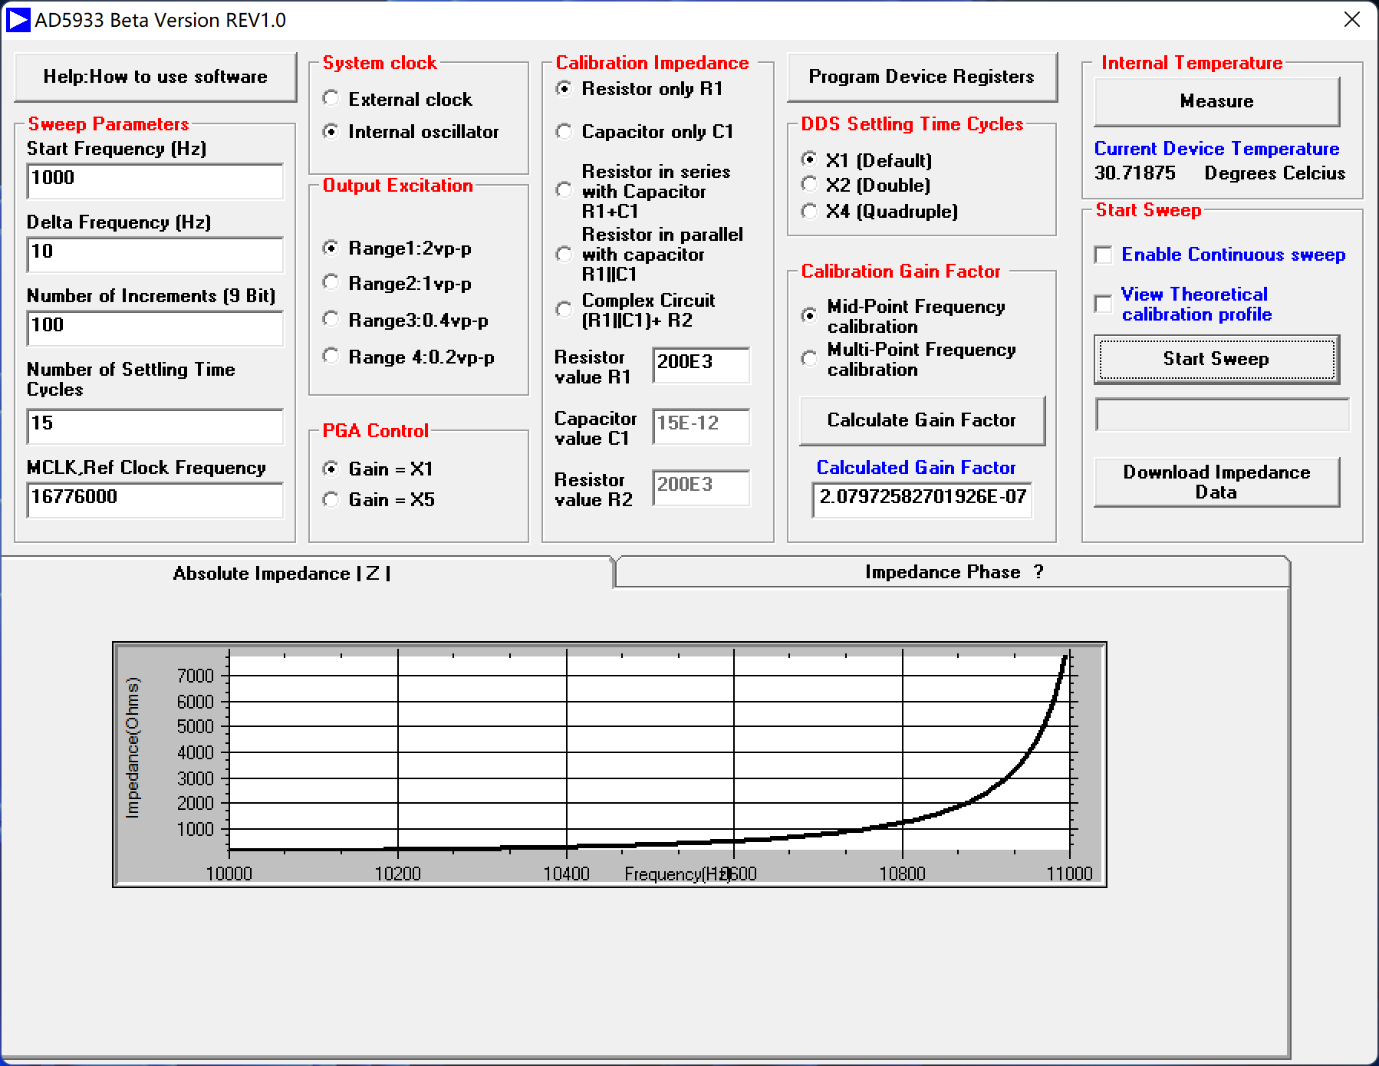
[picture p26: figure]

5 数据处理和机器学习

我们使用每帧28个特征点作为原始数据，无重复的对其中每一对数据做差得到378组数据，将这些数据集合进SVM训练，最终输出分类结果，并且产生了一些可视化效果以供鉴别过程中的正误。

四、成果总结

我们提出了一套识别手势的紧凑解决方案，巧妙地利用机器学习、图形学和医学影响方面的知识设计算法，同时设计了微型嵌入式系统和可靠的产品外观和结构，以期此技术能在无障碍交互如手语识别以及AR交互方面有所应用。

参考文献

骆维维. 《中国手语》手形研究[D].北京师范大学,2008

余江霞.简述中国手语

漆春. 中国手语的动作比较研究[D].大连理工大学,2014.

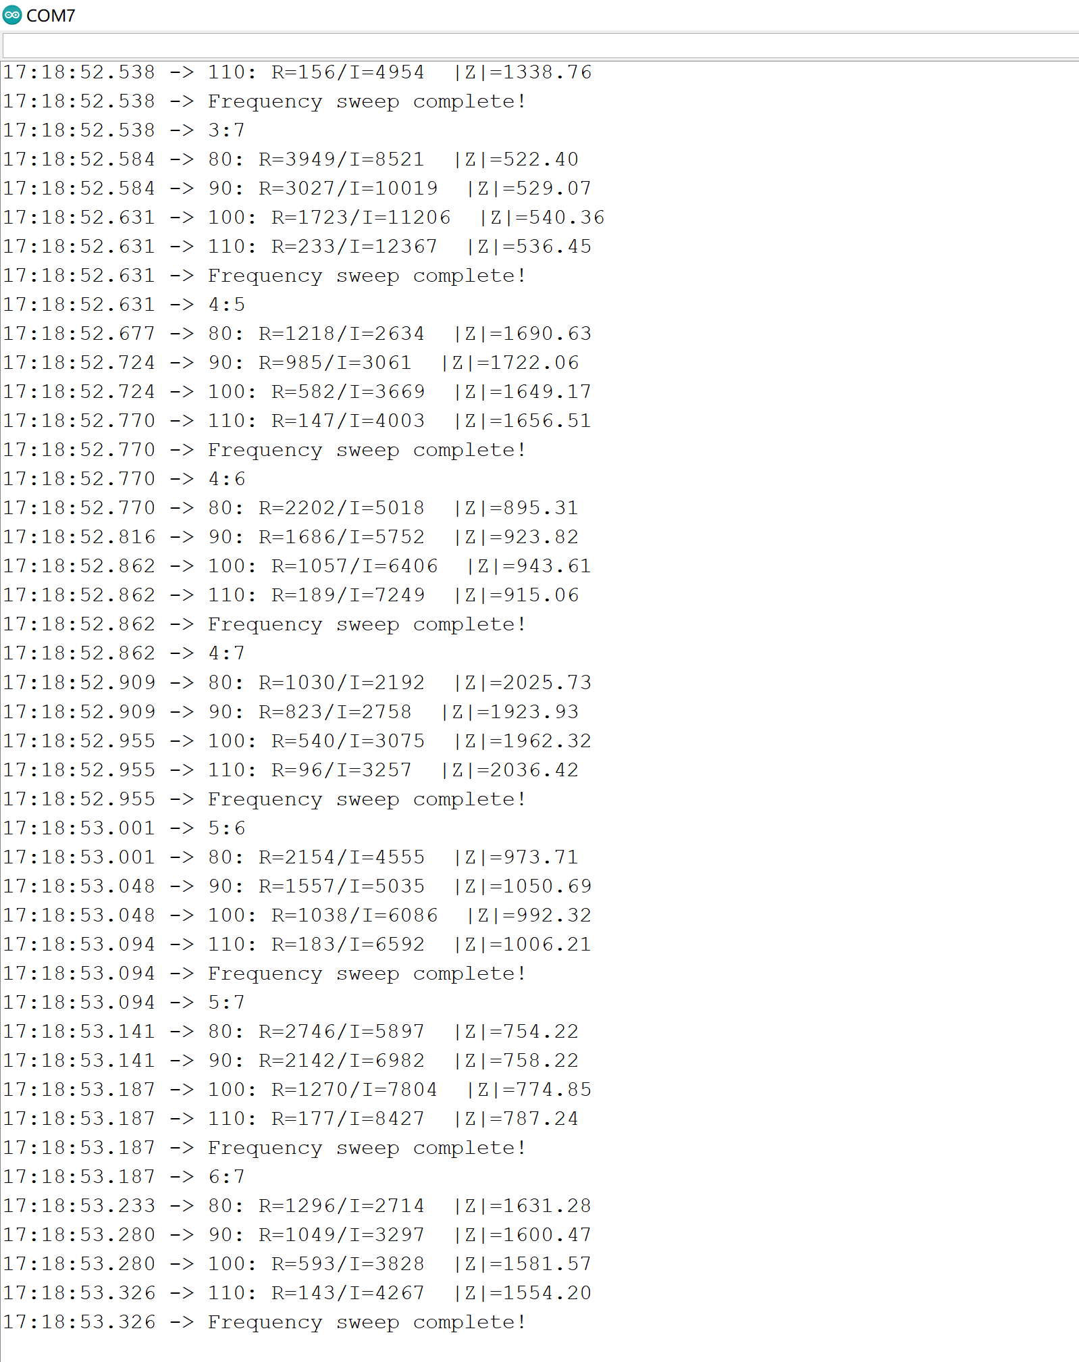
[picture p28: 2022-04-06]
AD5933Sweep/屏幕截图 2022-04-06 172450.png

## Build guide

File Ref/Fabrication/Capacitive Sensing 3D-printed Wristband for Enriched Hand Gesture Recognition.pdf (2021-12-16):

# Capacitive Sensing 3D-printed Wristband for Enriched Hand Gesture Recognition

## Hoang Truong, Phuc Nguyen, Anh Nguyen, Nam Bui and Tam Vu

University of Colorado Boulder

## {hoang.truong, vp.nguyen, anh.tl.nguyen, nam.bui, tam.vu}@colorado.edu

## ABSTRACT

In this work, we design a wearable-form hand gesture recognition system using capacitive sensing technique. Our proposed system includes a 3D printed wristband, capacitive sensors arrays in a flexible circuit board, a low-cost micro-controller unit and wireless communication module (BLE). In particular, the wristband manipulates the changes in capacitance from multiple capacitive sensors to recognize and detect users’ hand gestures. The software stack translates the detected gestures into control command for application layer, together with an user-friendly web interface that supports both data communication and training between the wristband and the host PC. We also release an open API of our designed system for future applications. Lastly, we envision our system open API will be available for developers to customize vast range of hand gesture and integrate the wristband into various applications, from command on remote computer to video game controller.

## Keywords

capacitive sensing; hand gesture recognition; 3D-printed wearable

## 1. INTRODUCTION

As human-computer-interaction experience evolves and IoT get smarter, consumers tend to prefer a more intuitive way to interact with computers other than just tapping or swiping on their smartdevices. Thus, more and more big names have joined the playground of voice or gesture control technology. Among these interesting trend, hand gesture recognition have been researched and manufactured in various forms of wearable devices such as wristband, gloves, and rings. The techniques behind those utilize wide range usage of sensors (e.g. motion [5], camera-based sensor [24], and etc.) or the measurement the signatures of human body such as impedance or muscle electrical signal, so called electromyography (EMG) [17].
While various manufactures and researches have been in the field for long time, each of them have to face up with a different numbers of drawbacks that make them modestly adopted universal. The drawbacks include (1) the need of easy to access and replicate the already published research, (2) the convenient and friendly UI for

Permission to make digital or hard copies of all or part of this work for personal or classroom use is granted without fee provided that copies are not made or distributed for profit or commercial advantage and that copies bear this notice and the full citation on the first page. Copyrights for components of this work owned by others than ACM must be honored. Abstracting with credit is permitted. To copy otherwise, or republish, to post on servers or to redistribute to lists, requires prior specific permission and/or a fee. Request permissions from permissions@acm.org.
WearSys’17, June 19, 2017, Niagara Falls, NY, USA
c 2017 ACM. ISBN 978-1-4503-4959-8/17/06. . . $15.00
DOI: http://dx.doi.org/10.1145/3089351.3089359

Flexible Circuit Board

Bottom View

Top View
Integrated
Wires

Integrated
Sensors

Integrated
Header

Silicon Bracelet Engineered From Scratch

Flexible Circuit Board
Embedded into Silicon

Figure 1: Overview of the proposed system
user experience, and (3) the high cost of the some commercial or DIY systems. Existing techniques have had their own pros and cons in which some of the stated drawbacks have been solved but not all. The ultimate aim for each products should lie on optimizing system in order to satisfy user experiences and open-source DIY devices for wide range of applications.
In this work, we introduce a hand gesture recognition system consisting of a capacitive-sensing-based wristband to sense the users’ hand movement, a low-cost micro-controller to record and manipulate measured data from sensors, a BLE component to communicate with application client and a software stack to train hand gesture patterns and export control command to application layer. There are many challenges in realizing such a system. First of all, the sensitivity of capacitive sensors makes the sensor reading fluctuate over time and be susceptible to noise. Second, the design sensors (i.e. number and arrangement of sensors, distance to users’ skin) must be aligned precisely. Too short distance leads to nearidentical readings for different gestures, and too far distance results in low resolution of measurement. Third, real-time communication is needed to determine users’ current gesture.
To address these challenges, we design a 3D printed wristband model with a complete system stack, and exploit support vector machine (SVM) method to differentiate the hand gestures. We make the following contributions in this work:
- Providing a system which includes both hardware and software designs with low-cost hardware components and open-source software stack for developers.
- Customizing sensor board design and layout using flexible circuit for precise measurement of sensor signal.
- Designing a capacitive sensing wristband and prototyping the flexible version by using 3D-printed molds.
In the following sections, we first present the fundamentals of capacitive sensing technique in Section 2. In Section 3 and Section 4, we describe in details the architecture, hardware design, and software stack of our proposed technique respectively. We provide the role of support vector machines in recognizing different trained gestures, and also present the application implementation based on our API. We conclude the paper with a discussion of related work and a summary.

## 2. CAPACITIVE SENSING BACKGROUND

Nowadays, capacitive sensing have become more and more pervasive, which has the wide range of presence, from daily life tools (control board buttons, car door handle and so on) to enormous use in smart phone touchscreen; and various application from touch recognition, proximity sensor to user identification and authentication [22, 12, 7]. In this section, we present the key principle of capacitive sensing technique. The capacitance change from sensor is usually measured indirectly from the changing in voltage, current, frequency or pulse width which are usually integrated into an application specific integrated circuit (ASIC). The variance in voltage, current, frequency or pulses is used to infer the sensor measurement.
In so-called ‘direct’ capacity sensing method, the key idea is to charge the capacitor from a defined current source for a known time and the voltage will be measured across the capacitor subsequently. This method needs a current source at very low and highly precise source. The next technique is to create an RC oscillator using the capacitor, and after that measures the time constant, frequency, or period. Although this method does not always generate high accurate results; it is easy and straightforward. Another method worth mentioning here is the one exploiting capacitor’s AC impedance. A sine-wave source excites the capacitance, and the capacitor’s current and voltage are measured. Nevertheless, the circuit is very complicated and experiences the highest part count. In addition, applying a charge amplifier that converts the ratio of the sensor capacitor to a reference capacitor into a voltage is also a common way for measuring of high precision, low-capacitance sensors.

Output to
processing MCU

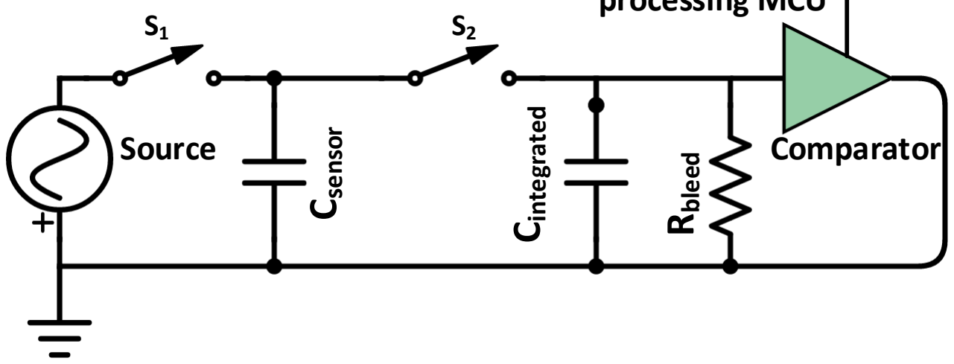
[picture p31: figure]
Csensor; Source; Cintegrated; Rbleed; Comparator

Figure 2: Capacitive sensing under-layer circuit

While surveying multiple capacitve sensing methods such as Microchip Capacitive Sensing Module [9], Charge Time Measurement Unit [11], Capacitive Voltage Divider [10]; Cypress CapSense Sigma Delta Modulation [4] or Silicon Labs Relaxation Oscillator [16]; we generalize the most common pattern of the underlying sensing circuit. Most common parts of the sensing circuit consist of a driving source, a sensor capacitor, an integration capacitor, a bleeding resistor and a comparator (Figure 2). The driving source is usually used to charge the sensor capacitor up to certain threshold during the closing period of switch S1. Next, the integration capacitor and bleeding resistor exist to discharge the sensor capacitor while switch S2 is closed. Finally, a comparator which is connected to ADC component of MCU will transfer the comparison of parameters observed on bleeding resistor (i.e. voltage, voltage difference or frequency changing) to process further in order to give the decision of capacitive sensor measurement.
In the open capacitor design, the sensor is considered as one side of the capacitor plate, the external contacting point will act as the second one (skin of the user in most of the cases). In our scenario, the users’ hand movement causes the compression of the silicone wristband, which lead to a change in distance from the user’s skin to the sensors and changes in capacitance.

## 3. SYSTEM DESIGN 3.1 System architecture

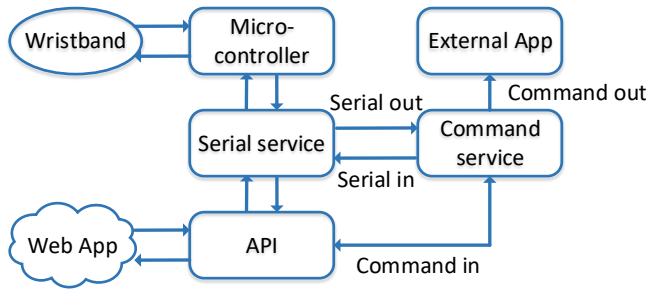
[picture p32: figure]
Wristband; Micro-; controller; Serial service; Command; service; External App; Web App; API; Serial out; Serial in; Command out; Command in

Figure 3: Overview of the proposed system
Our system envisions a wearable wristband that is able to determine the user’s current hand gesture, thus control external application or remote devices. The system architecture can be seen in Figure 3. Each movement of users’ hand will cause the change in capacitance which is measured from sensors on the wristband. The wristband with micro-controller unit and sensors are controlled via a wired serial connection. The micro-controller receives the single-byte command from the host device and processes one of the following action: response connection checking, update baseline measurements of all capacitive sensors, collect data from sensors and transfer to host device. The host device then processes the streamed data based on two modes: training gesture or consuming gesture events. The training gesture process takes the input capacitive measurement from the sensors, and then extract its features using SVM technique. We implement a web interface to make the training process more friendly to user while the key classification algorithm is run in the background server of the web app. Then, the recognized gesture will be consumed and translated to corresponding actions for specific applications (e.g. gestures can be translated into key presses in Linux operating system). Figure 3 illustrates the overview of our system.
To provide a robust working prototype, the following components are carefully designed and tested:
- Silicone wristband created using 3D-printed molds.
- Custom sensor design and layout using flexible circuit board.
- Micro-controller serial communication protocol to stream sensor readings.
- Host application and API leveraging machine learning to determine gestures from raw sensor readings.
- Client application using web technologies to present a clean UI for device management and remote control via gestures. In the following subsection, we will present the design of above components more in details.

## 3.2 Hardware design

3D printed wristband mold. To adapt a wristband that is user-friendly and satisfy the sensitivity of the capacitive sensors, we have tried multiple combination of materials and number of sensors. Each later version boosts improvement of sensor reading resolution by increasing of numbers of sensors and reduce noise due to the interaction of the different materials with users’ skin. Figure 4 shows the evolution stages of the wristband design. The mold of the wristband is designed as shown in figure 5a in order to hold the flexible circuit inside concretely. The molds is created using 3D printer and filled with silicone. After that, the copper sensors are placed inside the mold before allowing the silicone to settle.

(a) Nylon band | (b) Rubber band
(c) Silicon band | (d) Dragon skin band
Figure 4: The evolution of wristband design
Flexible circuit sensor board. With the design goal of highly sensitive, compact, unobtrusive for better user experience; and based on the given measurement of normal human wristband, the wristband is designed to hold up to sixteen sensors which are placed as eight pairs. This is the maximum number of sensors that we reach at the moment to fit in the size of human wrist. The more number of sensors using, the more noise and interference between sensors and wiring will be introduced. With eight pairs of sensor in place, embedded wiring and ribbon cables are designed in parallel and compactly for requirement of highly sensitivity but still sparse enough to also minimize the noise (Figure 6). Furthermore, the whole flexible circuit is dipped into Ferric Chloride solution for the purpose of etching and removing unwanted copper from the circuit board, which drastically reduces the effect of wiring and crosstalk interference.
Micro-controller unit (MCU) and BLE module. A specialized MCU is required to measure very small and highly sensitive changes in capacitance (approximately 100µF). We found that the Texas Instrument MSP430FR5969 [20], an ultra-low-power MCU, is fit to our needs. This MCU comes with low price and variety of supports including launch pad evaluation board and CapSense library [18] which are useful for capacitive sensor measurement and data manipulation. TI capacitive measurement method relied on relaxation oscillator technique, in which the internal ladder network is toggled due to the charge or discharge of the sensor capacitor. The frequency of oscillation [19] is related to sensor capacitance by: fosc =1/(1.386 ⇥ RC ⇥ Csensor), in which RC is the value of internal RC circuit. By counting the oscillation periods over a fixed frame duration, the frequency can be calculated and the sensor capacitance can be measured. The hardware device listens incoming serial data, interprets commands following our pre-defined configuration and responses with ack messages or measurement data

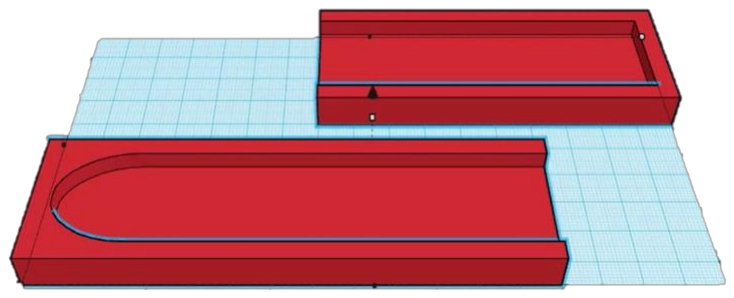
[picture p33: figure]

(a) Mold design

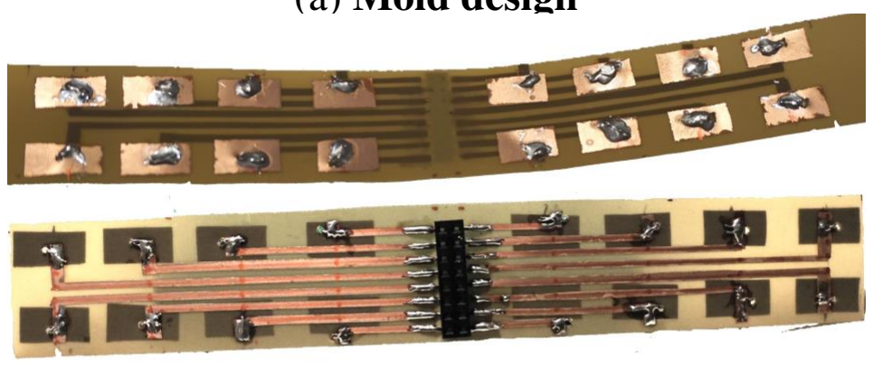
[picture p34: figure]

(b) Flexible circuit board Figure 5: 3D printed mold to hold the sensor board streaming. On top of that, two HC-05 BLE modules [6] together with a USB-TTL converter are also used as an alternative and unobtrusive way to stream measurement data to host device.
In the next section, we will present a software stack to augment all the hardware components together and also will provide examples working applications that we implemented.

## 4. IMPLEMENTATION 4.1 Software stack

The flow-chart of our software stack is presented in Figure 7. With the concrete design of hardware components, our software on the host device, which include multiple application layers, are implemented to (1) communicate with hardware on wristband, (2) receive streaming measurement data, (3) train and recognize gesture, and (4) translate gesture into specific consuming actions.
The host computer communicates with hardware on wristband via two-way serial communication. The host application, based on command line interface (CLI), searches for available serial ports, creates connections, and communicates with the wristband. Currently, the hardware is configured with the capability of responding to different flags from host computer, including echo, update baseline, train and stop commands. Echo command is used by the host to check if the wristband connection is still alive and ready to communicate. Update baseline command instructs the wristband to take new baseline measurements of all capacitive sensors with the given iteration parameter. This request blocks all other commands until baselining is complete. Train command allows the host device to collect data for a specific gesture with the input amount of measurement. When this command is received the wristband will flash a light to inform the user collection is about to begin. The user should perform the gesture and press a button to begin training. Finally, stop command halts measurement and put the hardware into an idle state.
Support vector machine (SVM). SVM is a binary linear classifier [1] represented by a decision boundary which is determined by the hyperplane constructed from sums of a kernel function:
P

d(x)=
xk2Y ↵ktkK(x, xk)+b where tk is the target output of +1 or -1, b is a bias parameter, Y is a set of support vectors. The support vectors xk corresponding to weight k are obtained by a quadratic optimization and satisfy the condition P
xk2Y ↵ktk =0, and xk > 0.
Given a data set, SVM can find the best separating hyperplane that maximizes the margin between the positive and negative classes. The kernel function K(.) is designed so that it can perform a nonlinear mapping from an input space into a higher dimensional space.

(a) Wiring | (b) Sensor placement | (c) Combine with header
Figure 6: Design of wiring and sensor placement with wire header

Html Angular
WebApp

Spring MVC
API

Publisher
Event
Generator

Subcriber
Control
Module

Controlled
Application

Connection
Manager

Connection
Status

Bluetooth
Connection
Command Routing Info Training

Events
Figure 7: Flow diagram of software layer

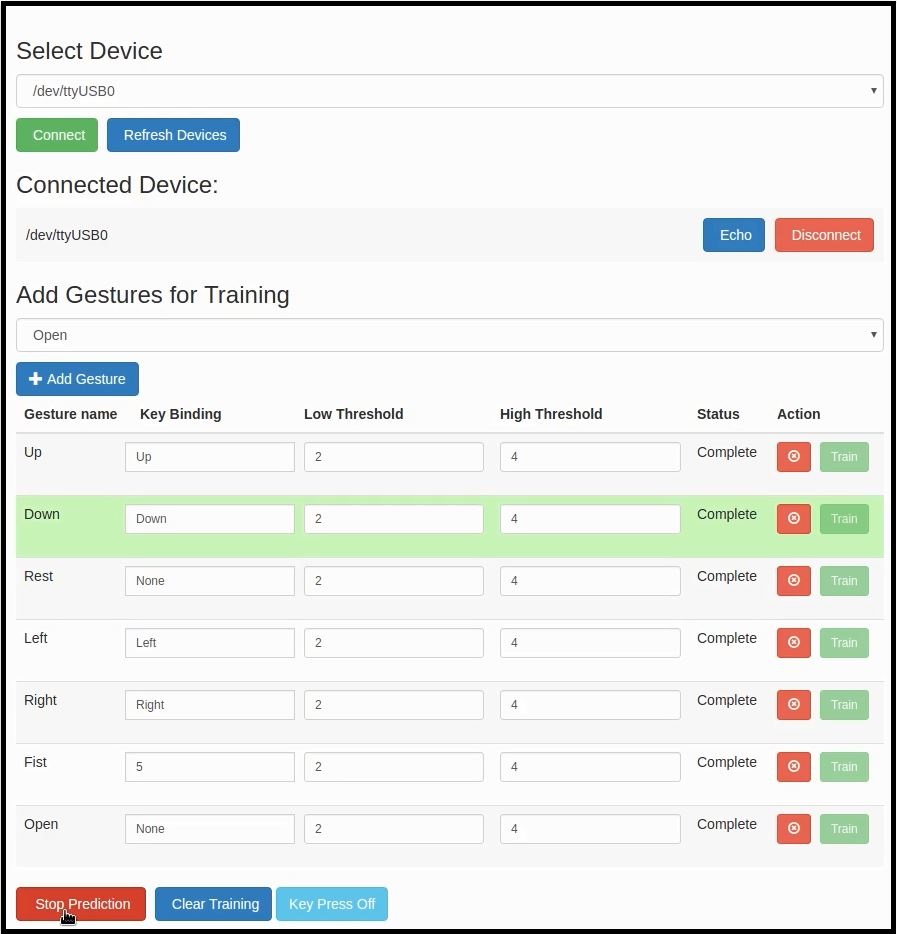
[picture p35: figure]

Figure 8: The Web User Interface for Training Different User’s Gestures

The output of K(.) is an inner product of two vectors in kernel feature space which is important for SVM learning. As we consider gesture recognition is a multi-class problem, our training technique is a binary classifier. Therefore, we only need to extend it to multi-class SVM. Generally, we can build binary classifiers which distinguish between one of the classes and the rest (one-versus-rest). The classification of a new sample for the one-versus-rest case is done by taking the class that has the largest positive distance.
In this paper, we apply the radial basis kernel functions for SVM classifier for hand gesture training because gesture recognition from noisy sensor reading requires a training process. With the knowledge of SVM, incoming data stream from hardware on wristband is received and converted to a proper format that can be used for training process. Trained and recognized gestures are managed by a web application that utilizes websockets for real-time communication (Figure 8. Currently pre-configured gesture set includes basic hand gestures: up, down, left, right, open palm and fist.

## 4.2 Implemented application

Current web application interface provides a core set of gestures, but can be easily customized to add more if needed. Each gesture thresholds can be tweaked in order to fit with the needed accuracy. Therefore, users and developers can add and customize different gestures, which is not limited to the six existed ones. The interface is simple and intuitive and the open API is available for developers to integrate the wristband into their application. The translation from hand gesture recognition to consuming events enables wide range of integration to external applications such as controlling remote mobile devices, issuing commands to remote computer or playing games from afar. We tested our system in Tetris game as shown in Figure 9. In this scenario, when pre-configured gestures are recognized, hand gestures events are consumed and translated into corresponding key presses in Linux operating system as up, down, left, right in order to play the game smoothly.

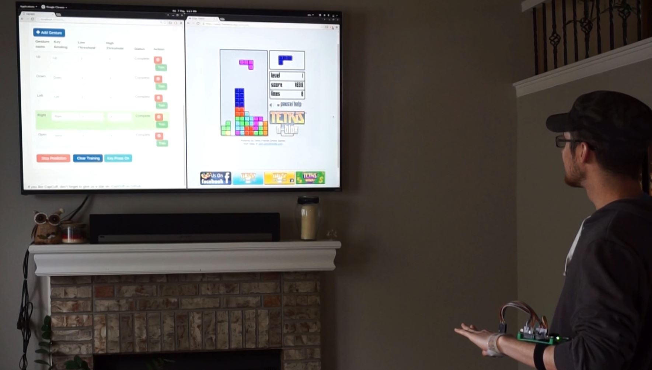
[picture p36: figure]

Figure 9: An example application of our designed wristband

## 5. RELATED WORKS

Sensor and gesture recognition with wearable devices. There are multiple researches on wearable sensor devices from MIT Media Lab such as Wristque [8] in which the wearable wristband consists multiple sensors such as localization sensor, motion sensor, light and humidity sensor; or the electromagnetic field detector bracelet [21] that senses the distance to the monitor display. Popular hand gestures that have been and recognized in previous researches can be classified as (1) realizing whole palm movement (fist, stretch, left, right), (2) counting number of fingers (thumbs, pointing fingers), and (3) configuration of open and close fingers (pinch gesture). These gesture can be recognized by measuring and calibrating data from outer skin source or inner skin source. Outer skin source measurements include the using of camera [15], attaching magnetic sensor or accelerometers and gyroscope to user’s wrist and finger [2], or collecting the contour of the moving wrist [3]. On the other hand, inner skin source method measures the muscle signal (EMG), i.e. Myo product [17]; or the impedance tomography (tomo [25] and tomo2 [26]).
Enriched gesture recognition. Based on previous hand gesture recognition methods, enriched gesture recognition is the next target with the aim for more precise and accurate detection for the bigger set of gestures. By exploiting capacitive sensing mechanism of touchscreen, [23] can estimate the pitch and yaw of the finger related to the touchscreen. Tomo shows the results of five hand-pinch gestures and eight whole-hand gesture with the high accuracy while using the device on wrist or arm. TypingRing [13] is a ring-like device allowing user to type on any surface so that input text from a group of 3 letters using 3 consecutive fingers.
Capacitive sensing based gesture recognition. The most relevant to our work consists of capacitive-sensor-based wearable devices. GestureWrist [14] utilized capacitive measurement of wristshape changes and forearm movement with the usage of a system with 6 receiver electrodes. The key technique here is to utilize the measurement of capacitance changes between those 6 receiver electrodes and 1 transmitter electrode on the top of the users’ wrist. This is different from what we proposed here since we measure the capacitance changes of capacitors which are formed by electrodes as 1 plate and human skin as the second plate. Furthermore, the GestureWrist is limited to the small number of capacitive sensors and not open to the consuming events for recognized gesture in application layer.

## 6. CONCLUSION

In this paper, we proposed a hand gesture recognition system utilizing capacitive sensing technique. We presented a 3D printed wristband-form device augmented sensor arrays under the flexible circuit board. We also provided a detail hardware and software interface of the proposed system. We envision that this technology can be easily integrated into a smart wristband or a smartwatch through an implemented application (Tetris game). More importantly, we would like to emphasize that our proposed technique can also be used for remote control aid (Presentation, Drone controllers, etc.) or assistance on game play devices among other applications.

Acknowledgements. This research was partially funded by NSF grant 1619392.

## 7. REFERENCES

[1] C. J. Burges. A tutorial on support vector machines for pattern recognition. Data Mining and Knowledge Discovery, 2:121–167, 1998.
[2] K.-Y. Chen, S. N. Patel, and S. Keller. Finexus: Tracking precise motions of multiple fingertips using magnetic sensing. In ACM CHI, pages 1504–1514, 2016.
[3] J. Cheng, O. Amft, G. Bahle, and P. Lukowicz. Designing Sensitive Wearable Capacitive Sensors for Activity Recognition. IEEE Sensors Journal, 13(10):3935–3947, 2013.
[4] Cypress. Sigma delta modulation. https://goo.gl/tercgu, 2017. [Online; accessed Apr 01, 2017].
[5] S. Fong, J. Liang, I. F. Jr., I. Fister, and S. Mohammed3. Gesture recognition from data streams of human motion sensor using accelerated pso swarm search feature selection algorithm. Journal of Sensors, 2015.
[6] HC-05. Bluetooth module. https://goo.gl/jsTccE, 2017. [Online; accessed Apr 01, 2017].
[7] M. Huynh, P. Nguyen, M. Gruteser, and T. Vu. POSTER: Mobile Device Identification by Leveraging Built-in Capacitive Signature. In ACM MobiCom, 2015.
[8] B. D. Mayton, N. Zhao, M. Aldrich, N. Gillian, and J. A. Paradiso. WristQue: A personal sensor wristband. In 2013 IEEE International Conference on Body Sensor Networks, pages 1–6, May 2013.
[9] Microchip. Capacitive sensing module (csm). https://goo.gl/mF1QBi, 2017. [Online; accessed Apr 01, 2017].
[10] Microchip. Capacitive voltage divider (cvd). https://goo.gl/9zpvFv, 2017. [Online; accessed Apr 01, 2017].
[11] Microchip. Charge time measurement unit (ctmu). https://goo.gl/saE0Wn, 2017. [Online; accessed Apr 01, 2017].
[12] P. Nguyen et al. Battery-Free Identification Token for Touch Sensing Devices. In ACM SenSys, pages 109–122, 2016.
[13] S. Nirjon, J. Gummeson, D. Gelb, and K.-H. Kim. TypingRing: A Wearable Ring Platform for Text Input. In ACM MobiSys, pages 227–239, 2015.
[14] J. Rekimoto. Gesturewrist and gesturepad: Unobtrusive wearable interaction devices. In Wearable Computers, 2001. Proceedings. Fifth International Symposium on, pages 21–27. IEEE, 2001.
[15] Z. Ren, J. Yuan, and Z. Zhang. Robust hand gesture recognition based on finger-earth mover’s distance with a commodity depth camera. In Proceedings of the 19th ACM international conference on Multimedia, pages 1093–1096. ACM, 2011.
[16] Silicon-Labs. Relaxation oscillator. https://goo.gl/1sAOzf, 2017. [Online; accessed Apr 01, 2017].
[17] Thalmic-Labs. Myo armband wearable guesture control. https://www.myo.com/, 2017. [Online; accessed Apr 04, 2017].
[18] TI. Capacitive touch software library. https://goo.gl/q5p1qm, 2017. [Online; accessed Apr 01, 2017].
[19] TI. Pcb-based capacitive touch sensing with msp430. https://goo.gl/MGD3XU, 2017. [Online; accessed Apr 01, 2017].
[20] TI. Ti msp430fr5969 datasheet. https://goo.gl/w0PPG9, 2017. [Online; accessed Apr 01, 2017].
[21] C. Vaucelle, H. Ishii, and J. A. Paradiso. Electromagnetic field detector bracelet. on ubiquitous Computing, page 109, 2008.
[22] T. Vu et al. Distinguishing users with capacitive touch communication. In ACM MobiCom, pages 197–208, 2012.
[23] R. Xiao, J. Schwarz, and C. Harrison. Estimating 3d finger angle on commodity touchscreens. In Proceedings of the 2015 International Conference on Interactive Tabletops & Surfaces, pages 47–50. ACM, 2015.
[24] M. Ye, X. Wang, R. Yang, L. Ren, and M. Pollefeys. Accurate 3d pose estimation from a single depth image. In 2011 International Conference on Computer Vision, pages 731–738, 2011.
[25] Y. Zhang and C. Harrison. Tomo: Wearable, Low-Cost Electrical Impedance Tomography for Hand Gesture Recognition. In ACM UIST, pages 167–173, 2015.
[26] Y. Zhang, R. Xiao, and C. Harrison. Advancing Hand Gesture Recognition with High Resolution Electrical Impedance Tomography. In ACM UIST, pages 843–850, 2016.

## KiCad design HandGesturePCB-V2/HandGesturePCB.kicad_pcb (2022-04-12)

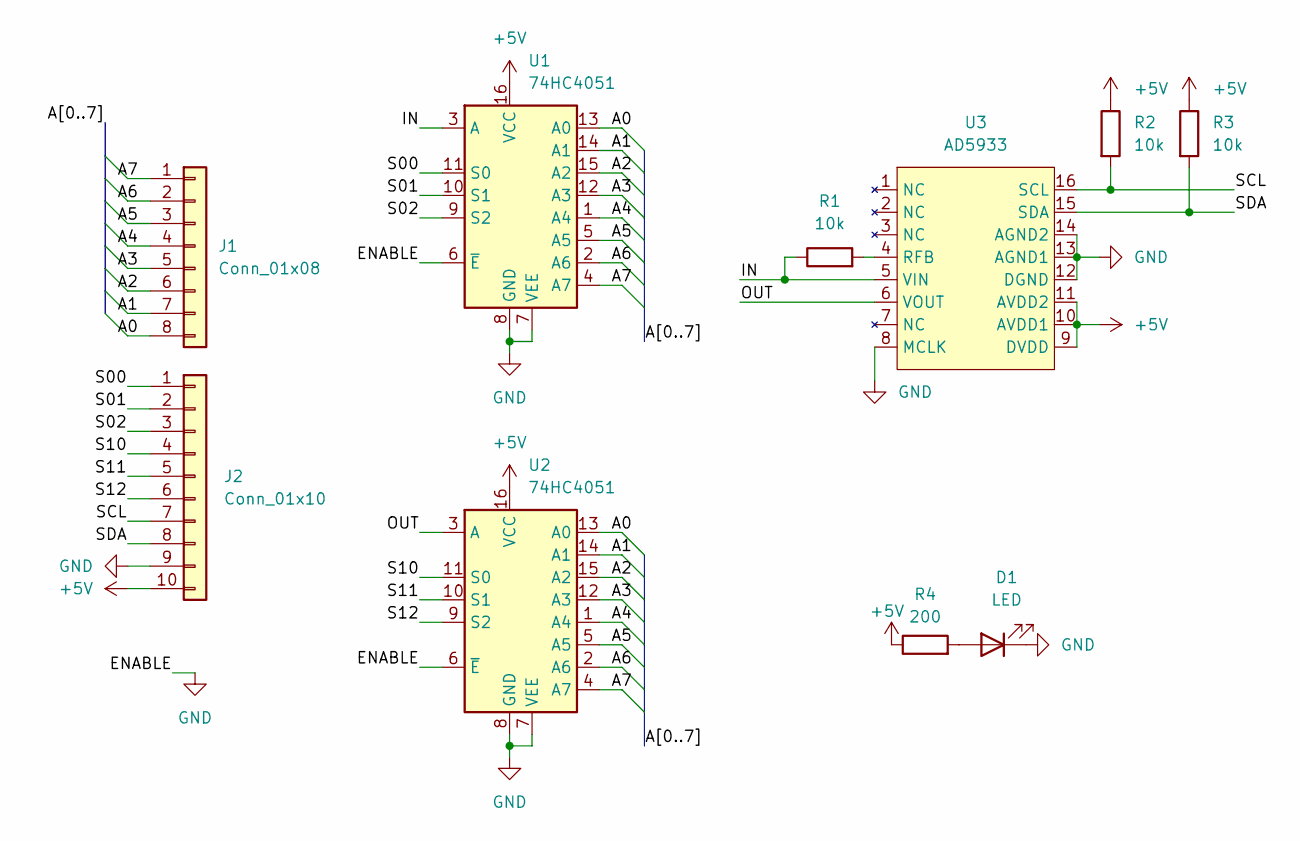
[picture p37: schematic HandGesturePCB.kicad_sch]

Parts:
D1: LED; LED_0603_1608Metric
J1: Conn_01x08; PinHeader_1x08_P2.54mm_Horizontal
J2: Conn_01x10; PinHeader_1x10_P2.54mm_Horizontal
R1, R2, R3: 10k; R_0603_1608Metric
R4: 200; R_0603_1608Metric
U1, U2: 74HC4051; TSSOP-16_4.4x5mm_P0.65mm
U3: AD5933; SSOP-16_5.3x6.2mm_P0.65mm

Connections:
+5V: J2.10, R2.1, R3.1, R4.1, U1.16 (VCC), U2.16 (VCC), U3.9 (DVDD), U3.10 (AVDD1), U3.11 (AVDD2)
/A0: J1.8, U1.13 (A0), U2.13 (A0)
/A1: J1.7, U1.14 (A1), U2.14 (A1)
/A2: J1.6, U1.15 (A2), U2.15 (A2)
/A3: J1.5, U1.12 (A3), U2.12 (A3)
/A4: J1.4, U1.1 (A4), U2.1 (A4)
/A5: J1.3, U1.5 (A5), U2.5 (A5)
/A6: J1.2, U1.2 (A6), U2.2 (A6)
/A7: J1.1, U1.4 (A7), U2.4 (A7)
/IN: R1.1, U1.3 (A), U3.5 (VIN)
/OUT: U2.3 (A), U3.6 (VOUT)
/S00: J2.1, U1.11 (S0)
/S01: J2.2, U1.10 (S1)
/S02: J2.3, U1.9 (S2)
/S10: J2.4, U2.11 (S0)
/S11: J2.5, U2.10 (S1)
/S12: J2.6, U2.9 (S2)
/SCL: J2.7, R2.2, U3.16 (SCL)
/SDA: J2.8, R3.2, U3.15 (SDA)
GND: D1.1 (K), J2.9, U1.6 (~E), U1.7 (VEE), U1.8 (GND), U2.6 (~E), U2.7 (VEE), U2.8 (GND), U3.8 (MCLK), U3.12 (DGND), U3.13 (AGND1), U3.14 (AGND2)
unnamed: D1.2 (A), R4.2
unnamed: R1.2, U3.4 (RFB)

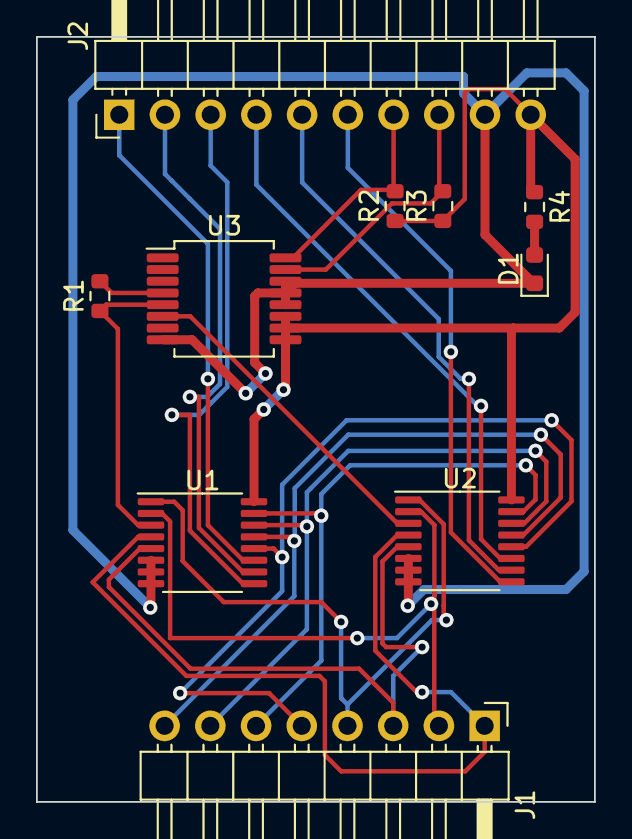
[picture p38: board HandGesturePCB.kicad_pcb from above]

Board: 2 copper layers, 31.0 x 42.5 mm, 10 parts (0 on the bottom side), 22 nets.

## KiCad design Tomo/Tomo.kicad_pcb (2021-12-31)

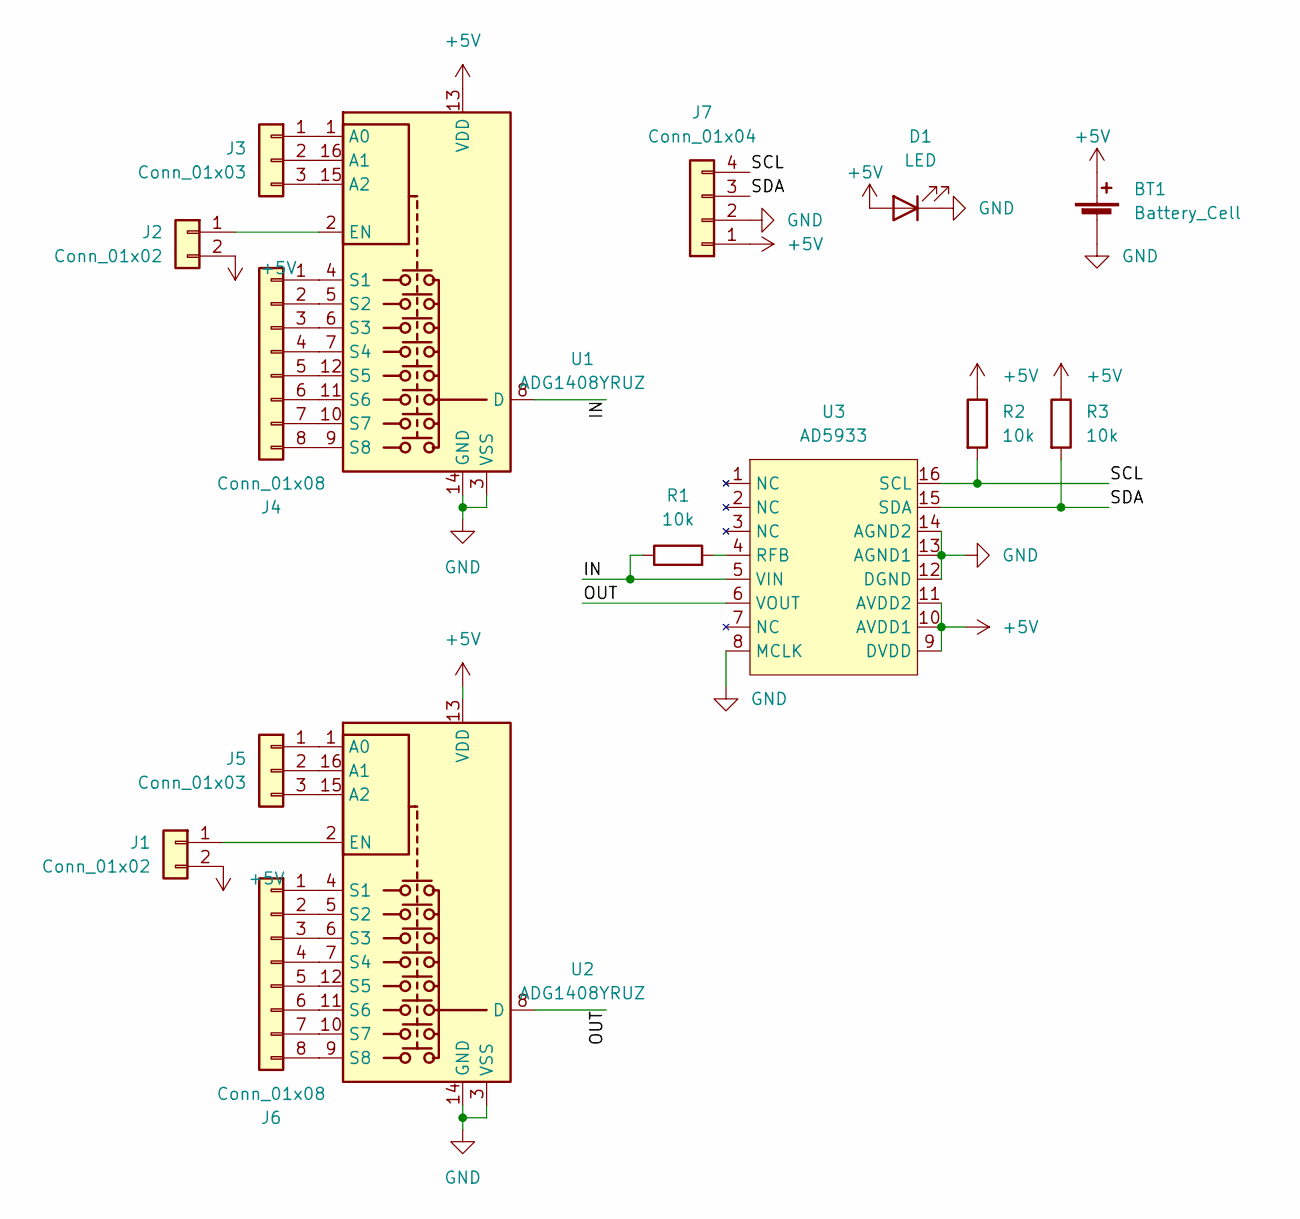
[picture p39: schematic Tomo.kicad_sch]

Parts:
BT1: Battery_Cell; PinHeader_1x02_P2.54mm_Vertical
D1: LED
J1, J2: Conn_01x02; PinSocket_1x02_P2.54mm_Vertical
J3, J5: Conn_01x03; PinSocket_1x03_P2.54mm_Vertical
J4, J6: Conn_01x08; PinSocket_1x08_P2.54mm_Vertical
J7: Conn_01x04; PinHeader_1x04_P2.54mm_Vertical
R1, R2, R3: 10k; R_0603_1608Metric
U1, U2: ADG1408YRUZ; TSSOP-16_4.4x5mm_P0.65mm
U3: AD5933; SSOP-16_5.3x6.2mm_P0.65mm

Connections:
+5V: BT1.1 (+), D1.2 (A), J1.2, J2.2, J7.1, R2.1, R3.1, U1.13 (VDD), U2.13 (VDD), U3.9 (DVDD), U3.10 (AVDD1), U3.11 (AVDD2)
/IN: R1.1, U1.8 (D), U3.5 (VIN)
/OUT: U2.8 (D), U3.6 (VOUT)
/SCL: J7.4, R2.2, U3.16 (SCL)
/SDA: J7.3, R3.2, U3.15 (SDA)
GND: BT1.2 (-), D1.1 (K), J7.2, U1.3 (VSS), U1.14 (GND), U2.3 (VSS), U2.14 (GND), U3.8 (MCLK), U3.12 (DGND), U3.13 (AGND1), U3.14 (AGND2)
unnamed: J1.1, U2.2 (EN)
unnamed: J2.1, U1.2 (EN)
unnamed: J3.1, U1.1 (A0)
unnamed: J3.2, U1.16 (A1)
unnamed: J3.3, U1.15 (A2)
unnamed: J4.1, U1.4 (S1)
unnamed: J4.2, U1.5 (S2)
unnamed: J4.3, U1.6 (S3)
unnamed: J4.4, U1.7 (S4)
unnamed: J4.5, U1.12 (S5)
unnamed: J4.6, U1.11 (S6)
unnamed: J4.7, U1.10 (S7)
unnamed: J4.8, U1.9 (S8)
unnamed: J5.1, U2.1 (A0)
unnamed: J5.2, U2.16 (A1)
unnamed: J5.3, U2.15 (A2)
unnamed: J6.1, U2.4 (S1)
unnamed: J6.2, U2.5 (S2)
unnamed: J6.3, U2.6 (S3)
unnamed: J6.4, U2.7 (S4)
unnamed: J6.5, U2.12 (S5)
unnamed: J6.6, U2.11 (S6)
unnamed: J6.7, U2.10 (S7)
unnamed: J6.8, U2.9 (S8)
unnamed: R1.2, U3.4 (RFB)

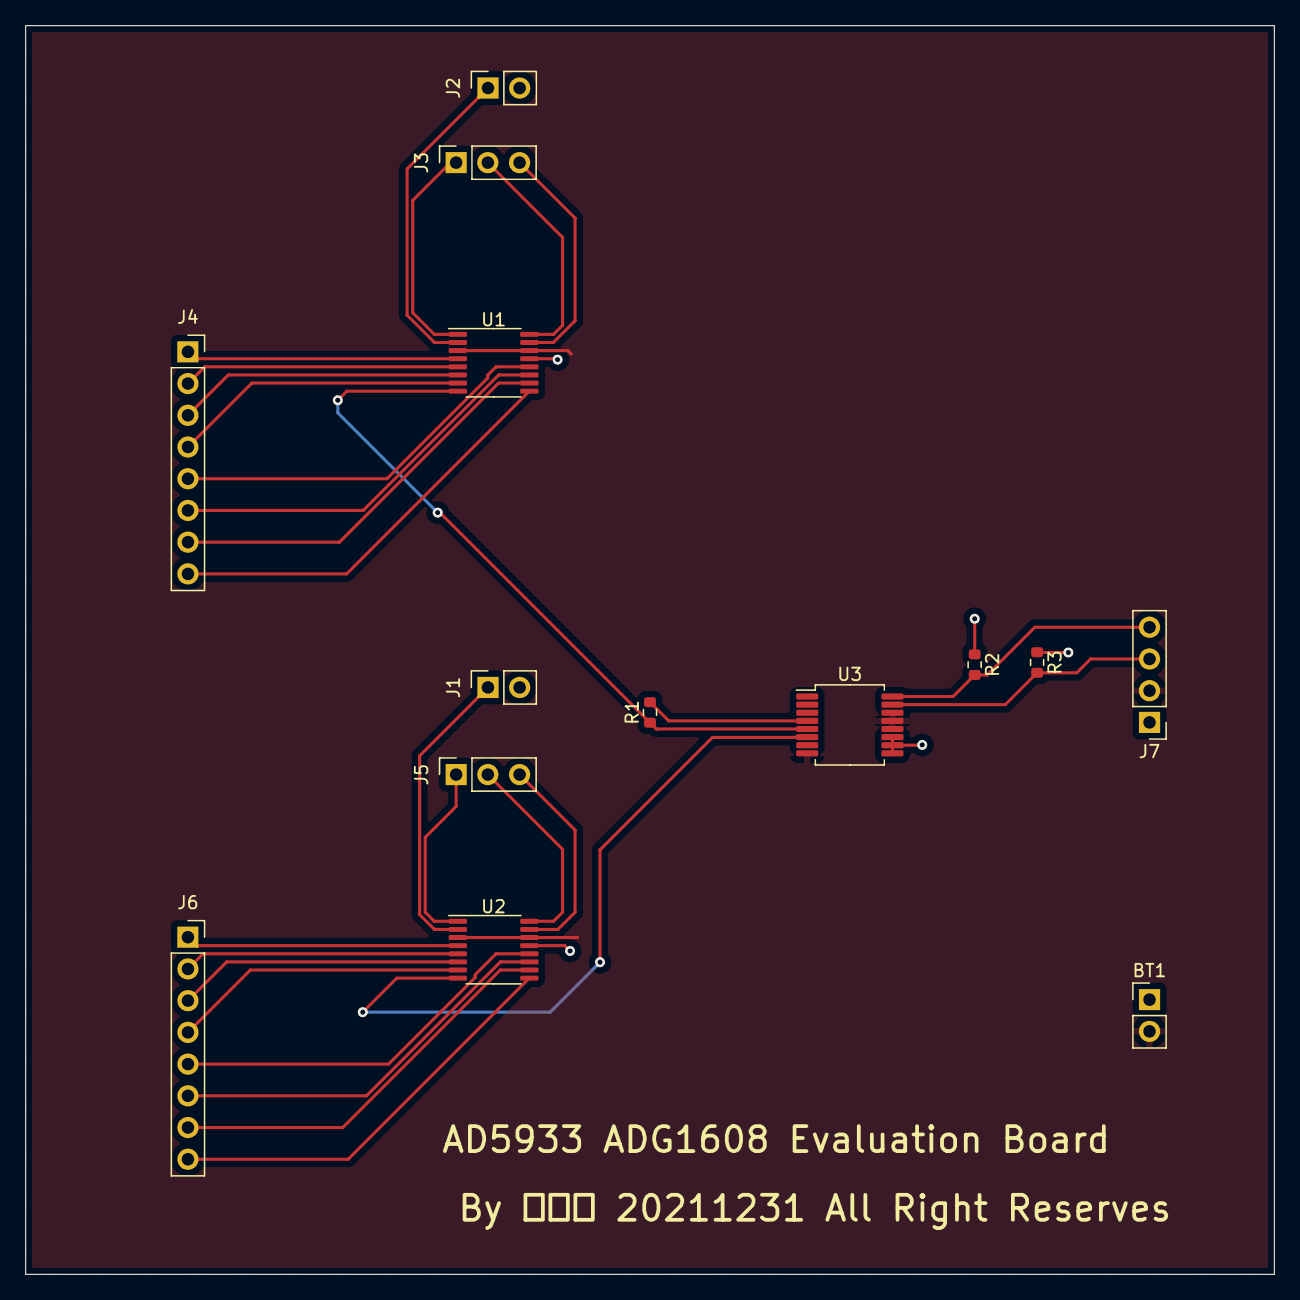
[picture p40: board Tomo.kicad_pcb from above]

Board: 2 copper layers, 100.0 x 100.0 mm, 14 parts (0 on the bottom side), 31 nets.

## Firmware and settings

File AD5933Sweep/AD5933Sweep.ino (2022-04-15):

/*
ad5933-test
    Reads impedance values from the AD5933 over I2C and prints them serially.
*/

//ESP32 I2C SDA default is GPIO 21,SCL default is GPIO 22

#include <Wire.h>
#include "AD5933.h"

#define START_FREQ  (400000)
#define FREQ_INCR   (100000)
#define NUM_INCR    (1)
#define REF_RESIST  (10000)

double gain[NUM_INCR+1];
int phase[NUM_INCR+1];

// 定义MUX的引脚
// ESP32-DevKit
//int MUX[]={16,17,18,25,26,27};
// Arduino Mega 2560
int MUX[]={2,3,4,5,6,7};

int* Decode83(int I){
  static int R[]={0,0,0};
  int R0=0;
  int R1=0;
  int R2=0;
  switch (I){
    case 0:{R0=0;R1=0;R2=0;break;}
    case 1:{R0=0;R1=0;R2=1;break;}
    case 2:{R0=0;R1=1;R2=0;break;}
    case 3:{R0=0;R1=1;R2=1;break;}
    case 4:{R0=1;R1=0;R2=0;break;}
    case 5:{R0=1;R1=0;R2=1;break;}
    case 6:{R0=1;R1=1;R2=0;break;}
    case 7:{R0=1;R1=1;R2=1;break;}
//    default:printf("error\n");
  }
  R[2]=R0;
  R[1]=R1;
  R[0]=R2;
//  Attention: S2 is High bit
  return R;
  }

void SetPort1(int P){
  int *R;
  R=Decode83(P);
  for (int i = 0; i < 3; i++ ){
    digitalWrite(MUX[i], R[i]);
  }
  }

void SetPort2(int P){
  int* R;
  R=Decode83(P);
  for (int i = 0; i < 3; i++ ){
    digitalWrite(MUX[i+3], R[i]);
  }
  }

void ClearPins(){
  for (int i = 0; i < 6; i++ ){
    digitalWrite(MUX[i], LOW);
  }
  }

void Link(int A, int B){
  SetPort1(A);
  SetPort2(B);
  Serial.print(A);
  Serial.print("-");
  Serial.print(B);
  Serial.print(":");
//  Serial.print("\n");
}

void SweepPort(){
  for (int i = 0; i < 8; i++ ){
    for (int j = i+1; j < 8; j++ ){
      Link(i,j);
      frequencySweepRaw();
    }
  }
  ClearPins();
  }



void setup(void)
{
  // Set MUX Output 
  for (int i = 0; i < 6; i++ ){
    pinMode(MUX[i], OUTPUT);
  }
  
  // Begin I2C
  Wire.begin();

  // Begin serial at 115200 baud for output
  Serial.begin(115200);
  Serial.println("AD5933 Test Started!");

  // Perform initial configuration. Fail if any one of these fail.
  if (!(AD5933::reset() &&
        AD5933::setInternalClock(true) &&
        AD5933::setStartFrequency(START_FREQ) &&
        AD5933::setIncrementFrequency(FREQ_INCR) &&
        AD5933::setNumberIncrements(NUM_INCR) &&
        AD5933::setPGAGain(PGA_GAIN_X1)))
        {
            Serial.println("FAILED in initialization!");
            while (true) ;
        }

  // Perform calibration sweep
  if (AD5933::calibrate(gain, phase, REF_RESIST, NUM_INCR+1))
    Serial.println("Calibrated!");
  else
    Serial.println("Calibration failed...");

  // Delay
  delay(1000);
}

void loop(void)
{
//  frequencySweepEasy();
  SweepPort();

//  // Delay
//  delay(1000);
  
//  // Easy to use method for frequency sweep
//  frequencySweepEasy();
//
//  // Delay
//  delay(5000);
//
//  // Complex but more robust method for frequency sweep
//  frequencySweepRaw();
//
//  // Delay
//  delay(5000);
}

// Easy way to do a frequency sweep. Does an entire frequency sweep at once and
// stores the data into arrays for processing afterwards. This is easy-to-use,
// but doesn't allow you to process data in real time.
void frequencySweepEasy() {
    // Create arrays to hold the data
    int real[NUM_INCR+1], imag[NUM_INCR+1];

    // Perform the frequency sweep
    if (AD5933::frequencySweep(real, imag, NUM_INCR+1)) {
      // Print the frequency data
      int cfreq = START_FREQ/1000;
      for (int i = 0; i < NUM_INCR+1; i++, cfreq += FREQ_INCR/1000) {
        // Print raw frequency data
        Serial.print(cfreq);
        Serial.print(": R=");
        Serial.print(real[i]);
        Serial.print("/I=");
        Serial.print(imag[i]);

        // Compute impedance
        double magnitude = sqrt(pow(real[i], 2) + pow(imag[i], 2));
        double impedance = 1/(magnitude*gain[i]);
        Serial.print("  |Z|=");
        Serial.println(impedance);
      }
      Serial.println("Frequency sweep complete!");
    } else {
      Serial.println("Frequency sweep failed...");
    }
}

// Removes the frequencySweep abstraction from above. This saves memory and
// allows for data to be processed in real time. However, it's more complex.
void frequencySweepRaw() {
    // Create variables to hold the impedance data and track frequency
    int real, imag, i = 0, cfreq = START_FREQ/1000;

    // Initialize the frequency sweep
    if (!(AD5933::setPowerMode(POWER_STANDBY) &&          // place in standby
          AD5933::setControlMode(CTRL_INIT_START_FREQ) && // init start freq
          AD5933::setControlMode(CTRL_START_FREQ_SWEEP))) // begin frequency sweep
         {
             Serial.println("Could not initialize frequency sweep...");
         }

    // Perform the actual sweep
    while ((AD5933::readStatusRegister() & STATUS_SWEEP_DONE) != STATUS_SWEEP_DONE) {
        // Get the frequency data for this frequency point
        if (!AD5933::getComplexData(&real, &imag)) {
            Serial.println("Could not get raw frequency data...");
        }

//        // Print out the frequency data
//        Serial.print(cfreq);
//        Serial.print(": R=");
//        Serial.print(real);
//        Serial.print("/I=");
//        Serial.print(imag);

        // Compute impedance
        double magnitude = sqrt(pow(real, 2) + pow(imag, 2));
        double impedance = 1/(magnitude*gain[i]);
//        Serial.print("  |Z|=");
//        Serial.println(impedance);
        if(i==NUM_INCR){
          Serial.println(impedance);
          }

        // Increment the frequency
        i++;
        cfreq += FREQ_INCR/1000;
        AD5933::setControlMode(CTRL_INCREMENT_FREQ);
    }
    
    
//    Serial.println("Frequency sweep complete!");

    // Set AD5933 power mode to standby when finished
    if (!AD5933::setPowerMode(POWER_STANDBY))
        Serial.println("Could not set to standby...");
}

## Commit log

2021-12-12 Create 附件3 2022年清华大学“大创”创业项目申报书-万雪鸽.doc
2021-12-12 Update 附件3 2022年清华大学“大创”创业项目申报书-万雪鸽.doc
2021-12-13 Create 附件2 项目信息汇总表.xlsx
    [附件2 项目信息汇总表.xlsx]
2021-12-13 Create 附件3 2022年清华大学“大创”创业项目申报书-万雪鸽(1).doc
2021-12-16 Create WristFlex Low-Power Gesture Input with Wrist-Worn 2642918.2647396.pdf
2021-12-16 Create Capacitive Sensing 3D-printed Wristband for Enriched Hand Gesture Recognition.pdf
2021-12-31 PCB Tomo
    [Tomo.kicad_pcb, Tomo.kicad_sch]
2022-03-13 pcb new ini
    [HandGesturePCB.kicad_pcb, HandGesturePCB.kicad_sch]
2022-03-16 清关材料
2022-03-20 Create 屏幕截图 2022-03-20 224517.png
2022-04-06 静电电了一下
